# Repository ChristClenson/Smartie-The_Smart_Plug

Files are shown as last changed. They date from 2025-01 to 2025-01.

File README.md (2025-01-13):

# Smartie - Smart Plug Socket

This repository contains the details of **Smartie**, an innovative smart plug developed as part of the Semester 4 EN2160 Electronic Design Realization module. Smartie combines convenience, energy management, and safety features to create a versatile addition to any smart home setup.

<div align="center">
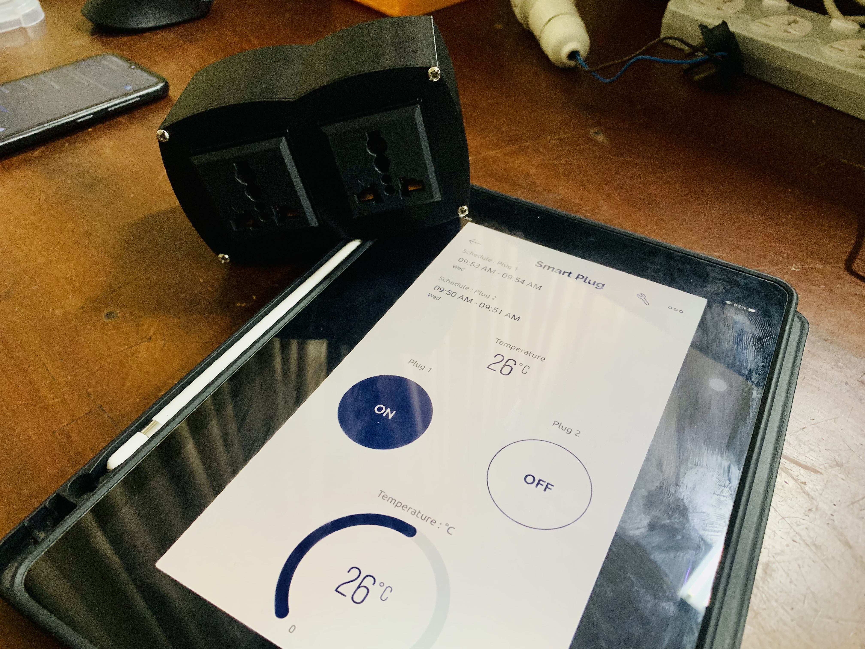
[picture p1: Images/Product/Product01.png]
Smartie
  
</div>

## Product Architecture
<div align="center">
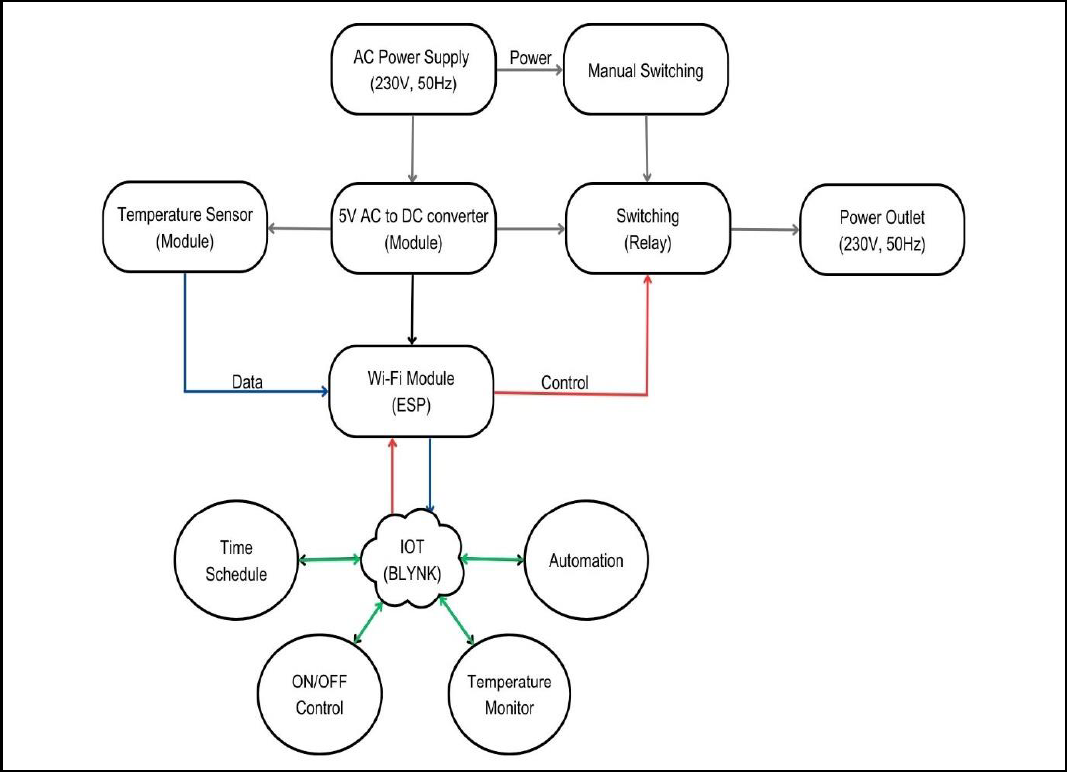
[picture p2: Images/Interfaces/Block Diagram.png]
Block Diagram
  
</div>

---

## Features

The **Smartie** smart plug offers a variety of advanced features designed for modern smart homes:

### 1. Wireless Control
Effortlessly manage devices and appliances remotely through a user-friendly mobile or web application. Whether at home or on the go, you can turn devices on or off with just a tap or click.

### 2. Temperature Monitoring
Keep track of the surrounding temperature in real-time via the mobile or web application. Monitor fluctuations and ensure optimal operating conditions.

### 3. Automatic Heating Protection
Ensure safety with the built-in heating protection feature. If the smart plug detects unusually high temperatures, it automatically cuts off power to the connected device to prevent hazards.

### 4. Time Scheduling
Set specific schedules for devices to operate automatically. From turning on the coffee maker in the morning to powering off devices at night, the scheduling feature helps save energy and simplifies daily routines.

---

## Purpose and Intended Usage

### 1. Remote Device Control
Control devices and appliances from anywhere using the mobile or web application. Turn devices on or off and monitor their status remotely, providing unparalleled convenience.

### 2. Energy Management
Optimize energy consumption by scheduling device usage. Reduce unnecessary power usage, lower utility bills, and contribute to a sustainable lifestyle.

### 3. Safety and Protection
Prevent overheating and electrical accidents with automatic heating protection. The plug continuously monitors the temperature and cuts off power when necessary, ensuring a secure environment.

---

## Target Users

- **Students**: Ideal for dormitories or apartments to efficiently manage devices and energy usage.
- **Homemakers**: Simplify daily routines and promote energy-saving practices.
- **Travelers**: Monitor and control home devices remotely for security and convenience.
- **Elderly or Disabled Individuals**: Increase accessibility and enable effortless device control.

---

## Mobile Application Specifications

The Smartie mobile application, powered by **Blynk 2.0**, enables seamless control and advanced functionality:

- Real-time remote control of devices.
- Temperature monitoring for safety and comfort.
- Automatic heating protection integration.
- Customizable time scheduling to optimize energy usage.

The application works in tandem with the **ESP8266 NodeMCU** and provides an intuitive interface for easy management of connected devices.

<div align="center">
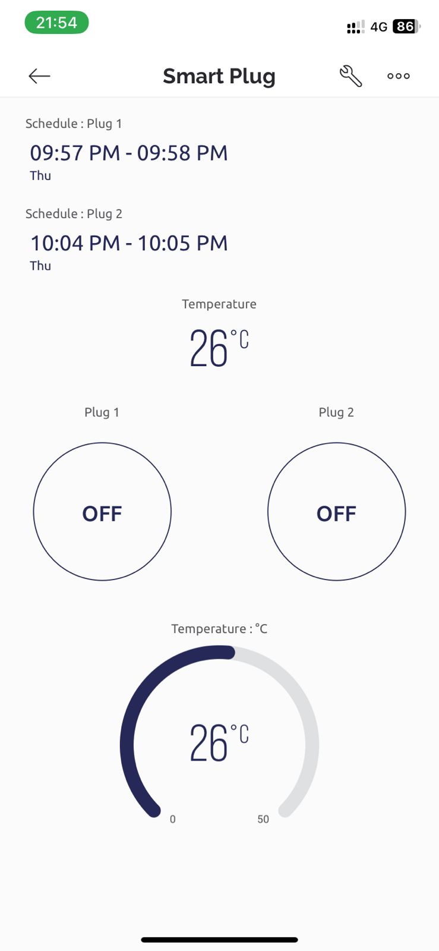
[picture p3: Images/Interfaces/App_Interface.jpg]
Blynk Interface
  
</div>

---

## Web Application Specifications

The Smartie web application, also powered by **Blynk 2.0**, extends device control to desktop or laptop browsers:

- Effortless control and monitoring of devices.
- Real-time status updates, temperature monitoring, and scheduling.
- Feature parity with the mobile application for a consistent user experience.

<div align="center">
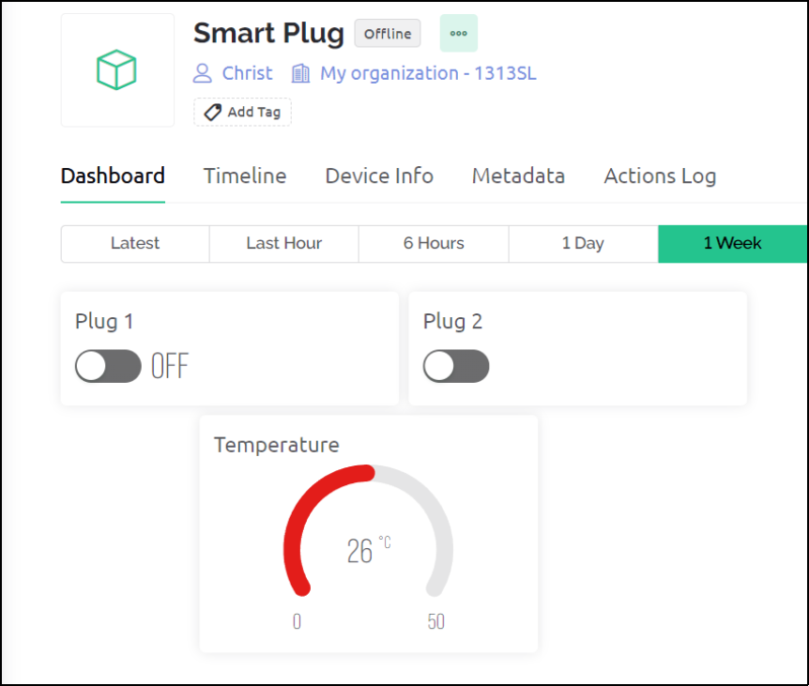
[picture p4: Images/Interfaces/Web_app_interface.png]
Web app Interface
  
</div>

---

## Technologies Used

- **ESP8266 NodeMCU**: Microcontroller for smart plug operation.
- **Blynk 2.0**: Platform for mobile and web application integration.
- **Temperature Sensor**: Monitors real-time temperature for safety features.

---
## Enclosure and PCB Designs

### Enclosure Design
<div align="center">
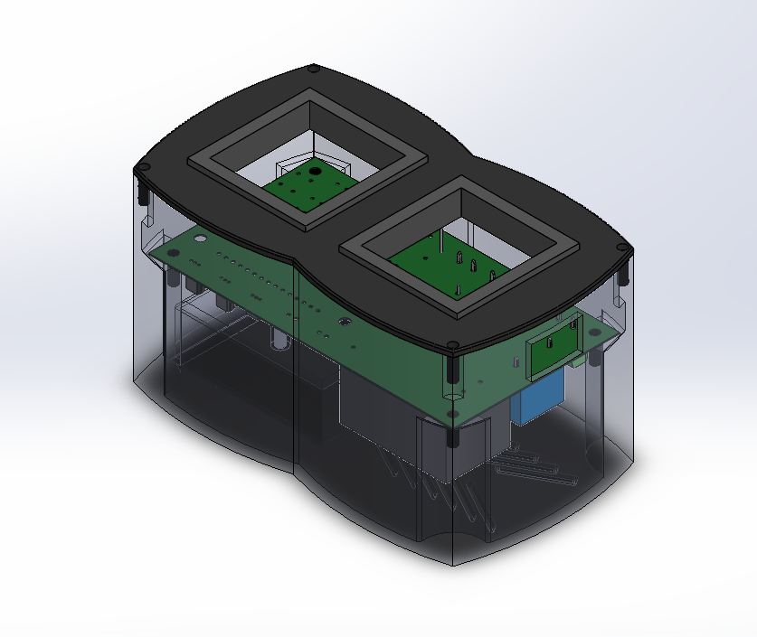
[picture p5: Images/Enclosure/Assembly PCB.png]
Enclosure
  
</div>

<div align="center">
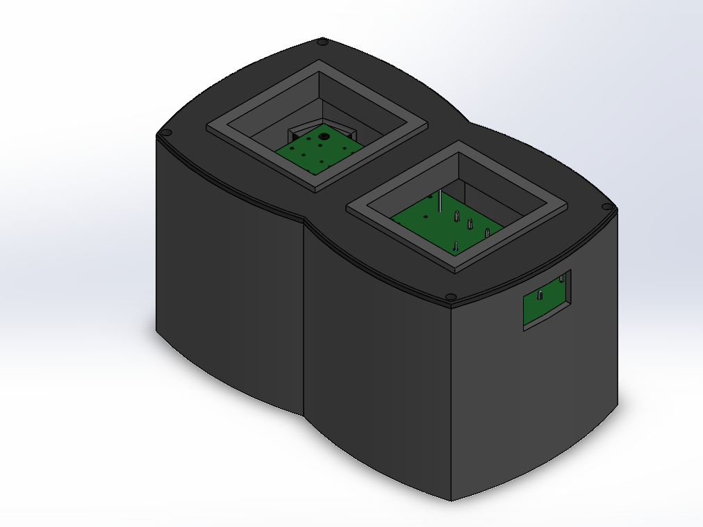
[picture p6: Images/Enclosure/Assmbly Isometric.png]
Enclosure
  
</div>

### PCB Design
<div align="center">
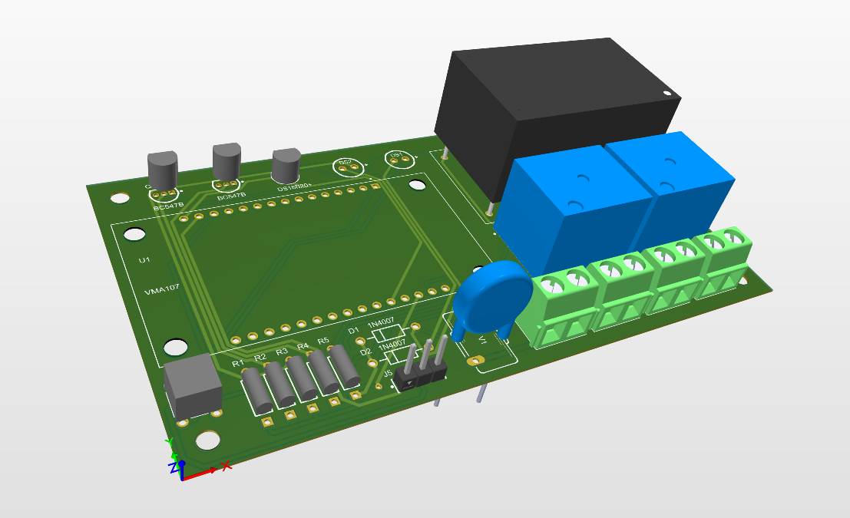
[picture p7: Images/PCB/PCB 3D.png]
PCB 3D
  
</div>

<div align="center">
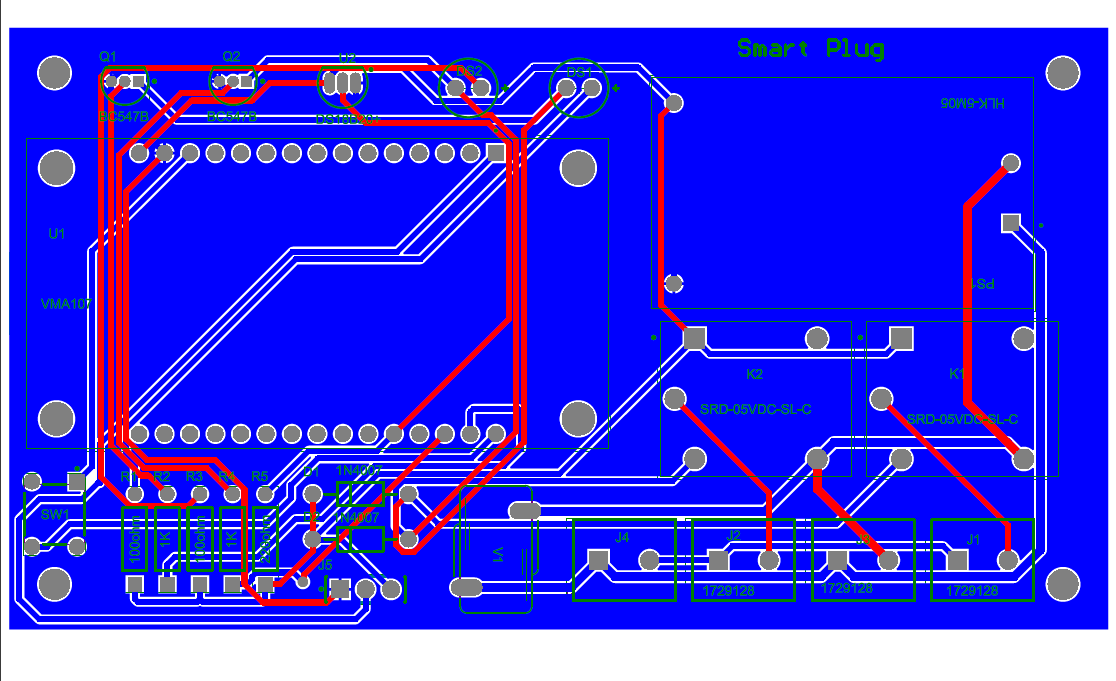
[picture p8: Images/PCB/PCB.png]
  
</div>

### Schematics Design
<div align="center">
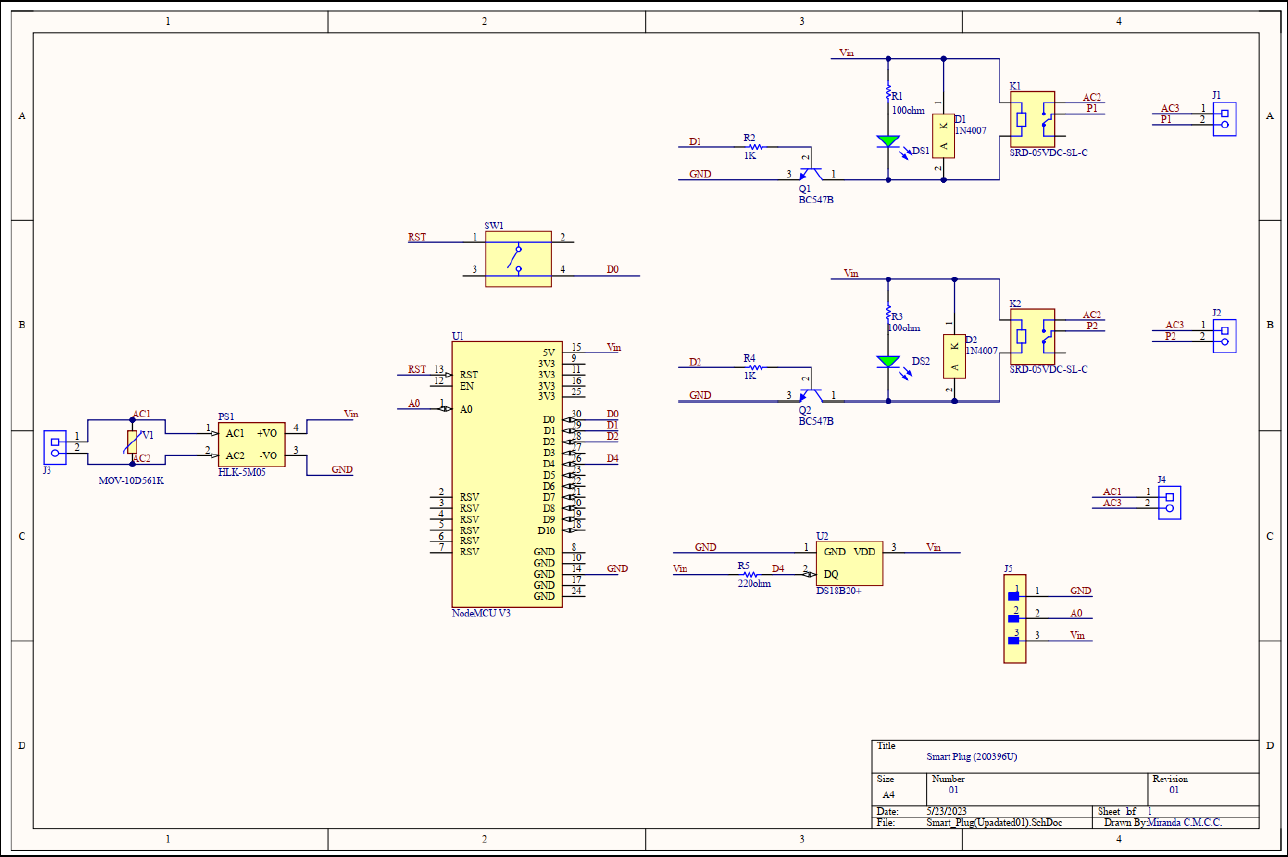
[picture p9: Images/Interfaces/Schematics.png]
  
</div>

---

## Conclusion

Smartie represents a significant step towards smarter and safer homes. With its innovative features, seamless control options, and focus on energy efficiency, it provides users with convenience, safety, and cost savings.

---

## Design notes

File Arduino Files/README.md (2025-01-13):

This directory contains the Arduino Code File for the Smart Plug.

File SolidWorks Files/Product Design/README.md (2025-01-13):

This directory contains the Enclosure Design Files of the Smart Plug.

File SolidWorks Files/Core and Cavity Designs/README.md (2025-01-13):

This directory contains the Core and Cavity Design Files for the Molds of the enclosure.

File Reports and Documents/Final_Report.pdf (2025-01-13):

## University of Moratuwa

## Department of Electronic and Telecommunication Engineering

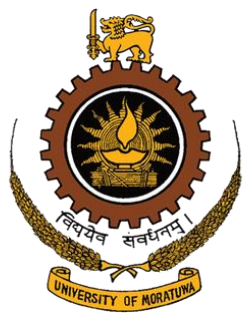
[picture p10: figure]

## EN2160 - Electronic Design Realization

## Final Report

Index No: 200396U

Name: Miranda C.M.C.C.

Product: Smart Plug

## 1. Abstraction

This report presents a concise overview of the smart plug's (also known as ‘Smartie’) development and assembly process. It includes the product description, specifications, schematics, BOM, PCB Gerber files, enclosure design, assembly instructions, and functionality testing procedures. This comprehensive guide serves as a valuable resource for understanding, replicating, and improving the smart plug's design.

Description and Specifications:

This section provides a detailed overview of the smart plug, including its functionality, target market, key features, and unique selling points. It also documents essential technical specifications, such as size, dimensions, hardware information and compatibility information.

Schematics, BOM, and PCB Gerber Files:

This section presents detailed circuit schematics for the smart plug, encompassing power supply and control circuitry. It includes a comprehensive Bill of Materials (BOM) with component names, part numbers, quantities, and sourcing information. Additionally, essential PCB Gerber files for manufacturing the printed circuit board are provided.

Enclosure Design Files:

This section provides a thorough description of the smart plug's enclosure design, featuring the 3D representations. It emphasizes user interface, material selection, and safety considerations.

Assembly and Installation Instructions:

This section offers a clear step-by-step guide for assembling the smart plug. It includes detailed instructions, accompanied by relevant images or diagrams. The assembly process covers component mounting on the PCB, enclosure assembly, and critical steps to build the final product. The installation instructions give the consumer the initial steps they need to follow to install the smart plug.

Functionality Testing:

This section outlines the testing process to ensure the smart plug's functionality. It includes procedures for verifying key features and compatibility with devices.

## Contents

## 2. Description and Specifications

## 2.1 Features

The 'Smartie' is an innovative smart plug socket that offers wireless control through a user-friendly mobile or web application. With advanced features such as temperature monitoring, automatic heating protection, and a convenient time scheduling feature, it's the perfect addition to any smart home setup.

Wireless Control:

With the 'Smartie' smart plug socket, we can effortlessly manage our devices and appliances remotely, providing us with enhanced convenience and control. Whether we're at home or on the go, mobile or web applications allow us to easily turn devices on or off with just a tap or click.

Temperature monitoring:

One of the standout features of the 'Smartie' is its temperature monitoring capability. We can use the mobile or web application to check the current temperature of smart plug’s surroundings and keep an eye on any fluctuations.

Automatic heating protection:

The 'Smartie' also comes equipped with automatic heating protection, providing an added layer of safety. If the plug socket detects unusually high temperatures, it will automatically cut off power to the connected device, preventing any potential hazards and ensuring peace of mind.

Time scheduling:

Additionally, the time scheduling feature allows us to set specific schedules for our devices. Whether it's turning on our coffee maker in the morning or automatically powering off our gaming console at night, we can customize the 'Smartie' to fit our daily routine. This feature helps us save energy, reduces utility bills, and adds convenience to our everyday life.

## 2.2 Purposes and Intendent Usage

Remote Device Control:

The primary purpose of Smartie is to provide users with the ability to remotely control their devices and appliances. Whether they're at home, at work, or away on vacation, they can easily manage their devices using the mobile or web application. This allows them to turn devices on or off, and monitor their status from anywhere, providing convenience and flexibility in managing their smart home.

Energy Management:

Smartie offers energy-saving benefits by allowing users to schedule device usage. With the time scheduling feature, they can set specific times for their devices to turn on or off automatically. This helps optimize energy consumption by ensuring that devices are only active when needed, reducing unnecessary power usage, and lowering utility bills.

Safety and Protection:

Smartie includes automatic heating protection mechanisms to ensure safety when using devices that generate heat. The plug socket continuously monitors the temperature, and if it detects excessively high levels, it will automatically cut off power to the connected device. This helps prevent overheating, reduces the risk of electrical accidents, and provides peace of mind for users.

## 2.3 Target Users

Students:

Students living in dormitories or apartments seek efficient ways to manage their devices, control energy usage, and enhance their living environment.

Homemakers:

Homemakers who are looking to simplify their daily routines, manage household devices remotely, and promote energy-saving practices.

Travelers:

Individuals who frequently travel and who want the ability to monitor and control their home devices remotely for security, energy efficiency, and convenience purposes.

Elderly or Disabled Individuals:

Smartie can offer increased accessibility and convenience for elderly or disabled individuals, allowing them to easily control devices without physical effort or mobility challenges.

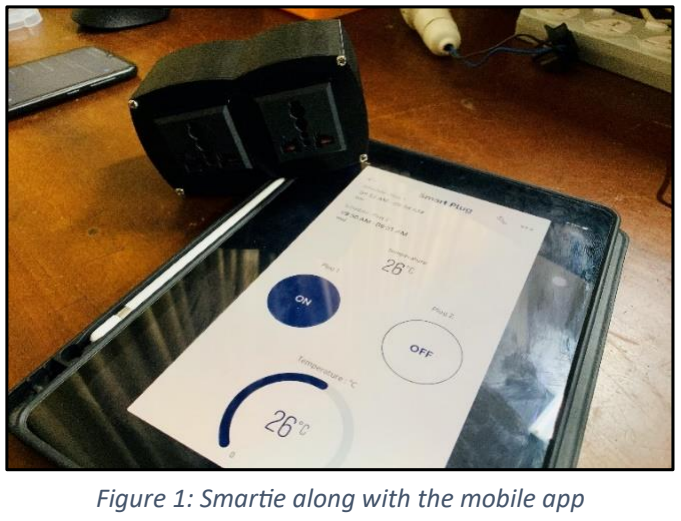
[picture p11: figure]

Figure 1: Smartie along with the mobile app

## 3. Product Specifications

## 3.1 Physical Specifications

- Dimension: 130mm x 70mm x 60mm
- Power inlet type: Square pin (Type G)
- Power outlet types: Square pin (Type G), Circular Pin (Type D)
- Development board: ESP 8266 NodeMCU

## 3.2 Development Board Specifications

The ESP8266 NodeMCU development board used in Smartie offers the following key specifications:

- ESP8266 Chip: Powered by the ESP8266 Wi-Fi module for wireless connectivity.
- Microcontroller: Includes a powerful microcontroller unit (MCU) for efficient

processing.

- Processing Power: Operates at up to 80MHz clock speed for fast execution of tasks.
- Memory: Provides onboard memory (4MB to 16MB) for program code and data

storage.

- GPIO Pins: Features GPIO pins for easy integration with external devices.
- Programming Interface: USB interface for programming and debugging.
- Arduino Compatibility: Arduino IDE compatibility for convenient development and

customization.

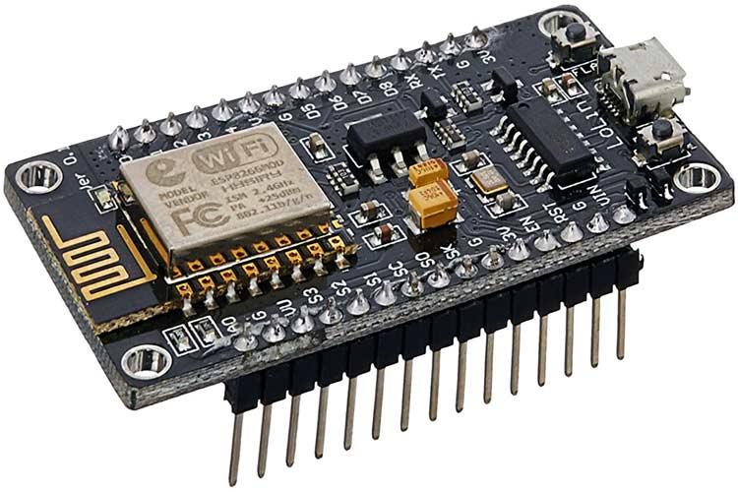
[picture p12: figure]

Figure 2: ESP8266 NodeMCU

## 3.3 Mobile Application specifications

The Smartie mobile application, powered by Blynk 2.0, brings seamless control and advanced features to our fingertips. Designed to work in tandem with the ESP8266 NodeMCU and Smartie's smart plug socket, this innovative application empowers us to effortlessly manage our devices and enhance our smart home experience.

The heart of the Smartie mobile application is Blynk 2.0, a powerful platform that enables intuitive and customizable control interfaces. With its user-friendly interface and extensive capabilities, Blynk 2.0 allows you to tap into the full potential of Smartie and its connected devices.

Through the mobile application, we gain real-time control over our devices, giving us the freedom to turn them on or off remotely with just a tap on our mobile screen. Whether we're at home or on the go, the convenience of managing our devices from the palm of our hand is now within reach.

It also integrates temperature monitoring functionality, providing us with instant access to real-time temperature readings. Stay informed about our surroundings and make informed decisions to maintain optimal comfort levels. With Blynk 2.0's seamless integration, Smartie can detect excessive temperatures and automatically cut off power to the connected devices, ensuring a secure environment for us and our home.

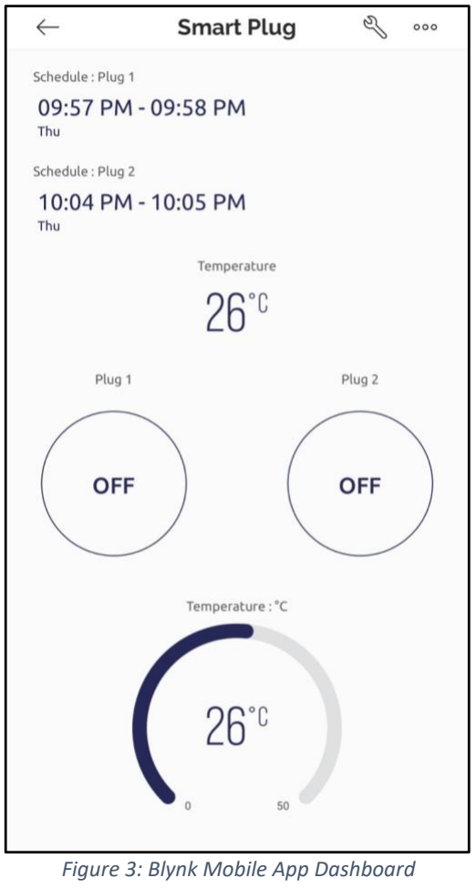
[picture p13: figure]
Figure 3: Blynk Mobile App Dashboard

## 3.4 Web Application specifications

Smartie web application, also powered by Blynk 2.0, which brings the same level of convenience and control to our desktop or laptop computer. With that we can seamlessly extend our device management capabilities beyond our mobile device and access them from the comfort of our web browser. Powered by the same robust Blynk 2.0 platform, the web application offers a familiar interface with additional functionalities and a larger screen real estate.

Just like its mobile counterpart, the web application allows us to effortlessly control and monitor our devices remotely. With a few clicks, we can turn devices on or off, adjust settings, and view real-time device status. Blynk 2.0's seamless integration ensures that the web application maintains feature parity with the mobile app. We can still benefit from temperature monitoring, automatic heating protection, time scheduling and notifications.

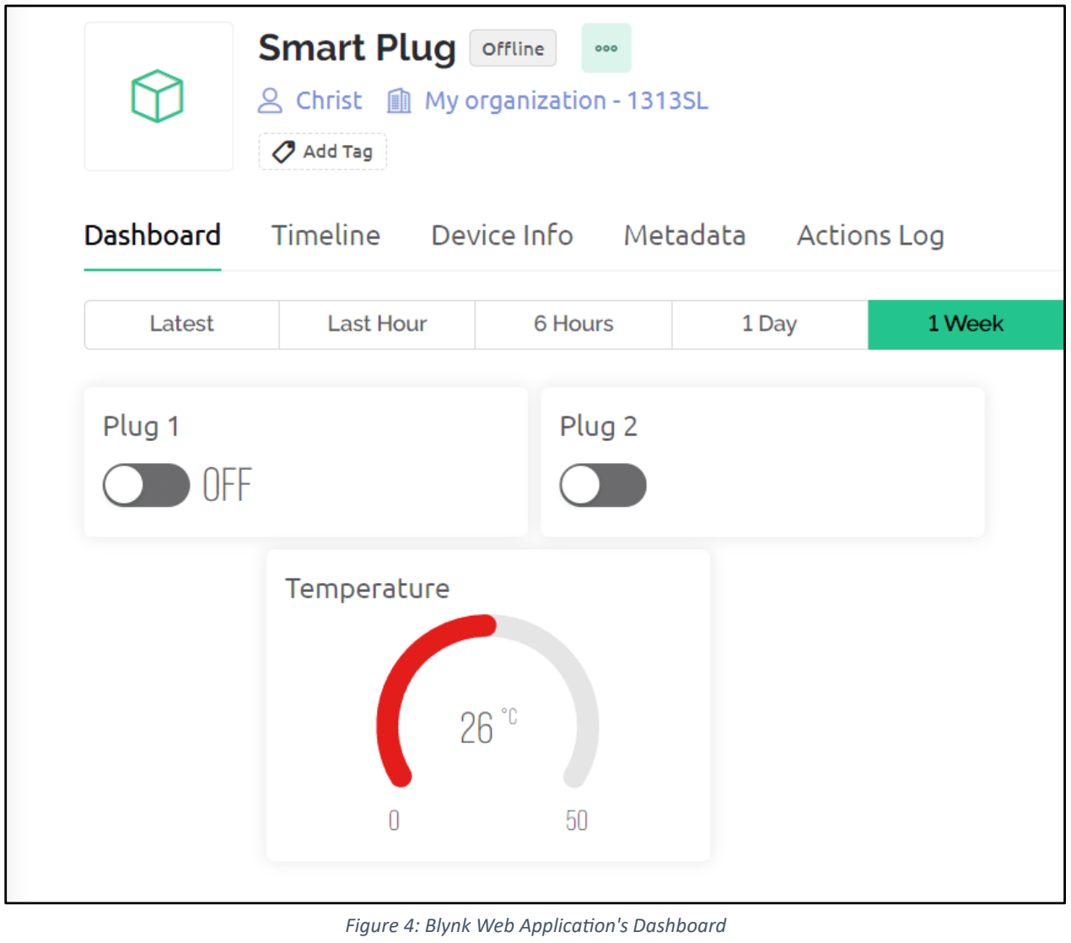
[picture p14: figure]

Figure 4: Blynk Web Application's Dashboard

## 4. Schematics, BOM, and PCB Gerber Files

## 4.1 Block Diagram

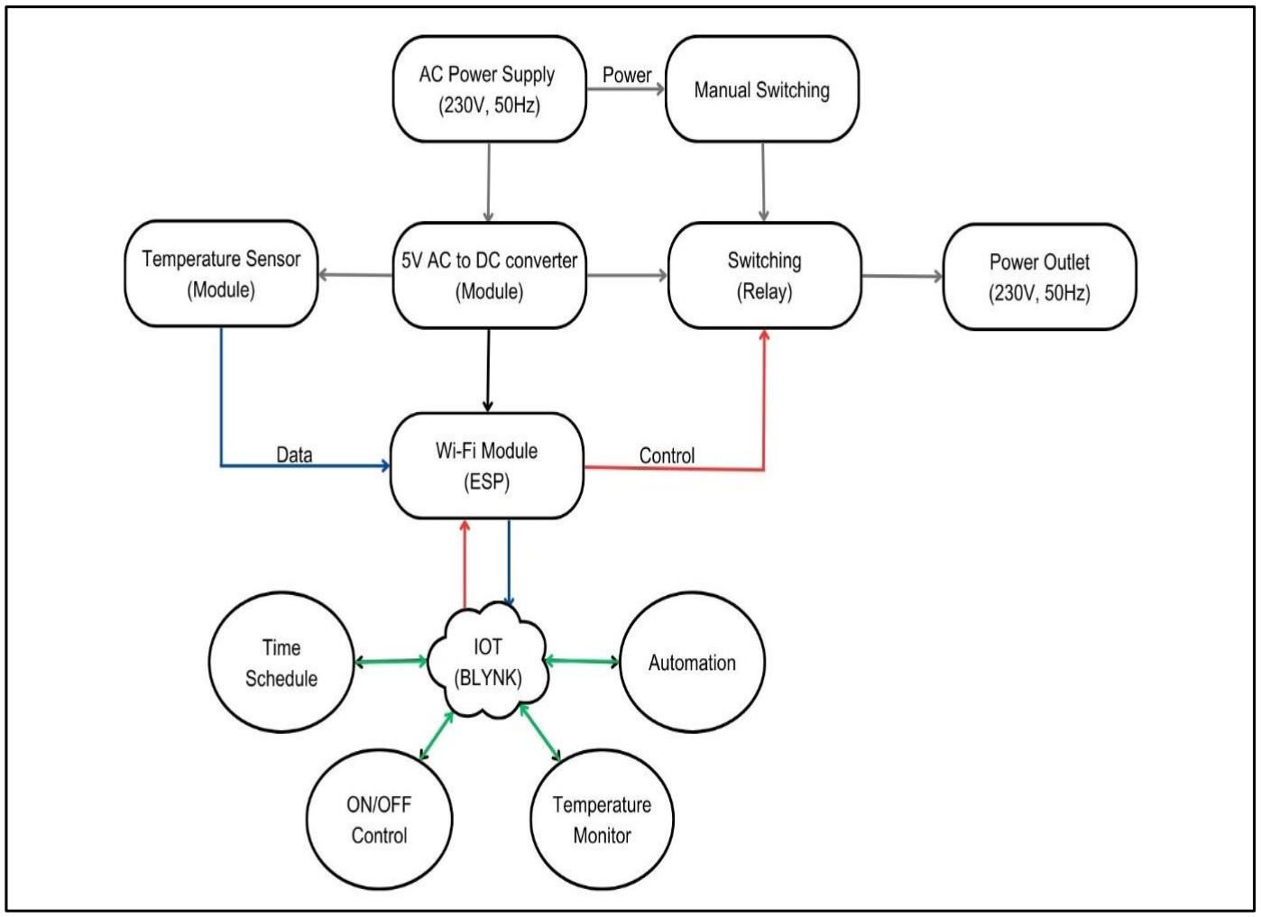
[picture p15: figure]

This is the initial block diagram that aligns with the product’s specifications. To ensure efficient power supply to the Wi-Fi module (ESP8266 NodeMCU), a single module that directly converts the 230V AC input to 5V DC is used. This approach not only contributes to a compact PCB design but also facilitates the overall compactness of the product. Consequently, it becomes more convenient to power both the Wi-Fi module and the temperature sensor within the smart plug.

The BLYNK IoT platform is used because of its user-friendly nature and simplistic user interface. This choice ensures easy setup and enhances the marketability of the product. Additionally, BLYNK offers all the desired features and functionalities I had envisioned for the smart plug.

## 4.2 Schematic Design

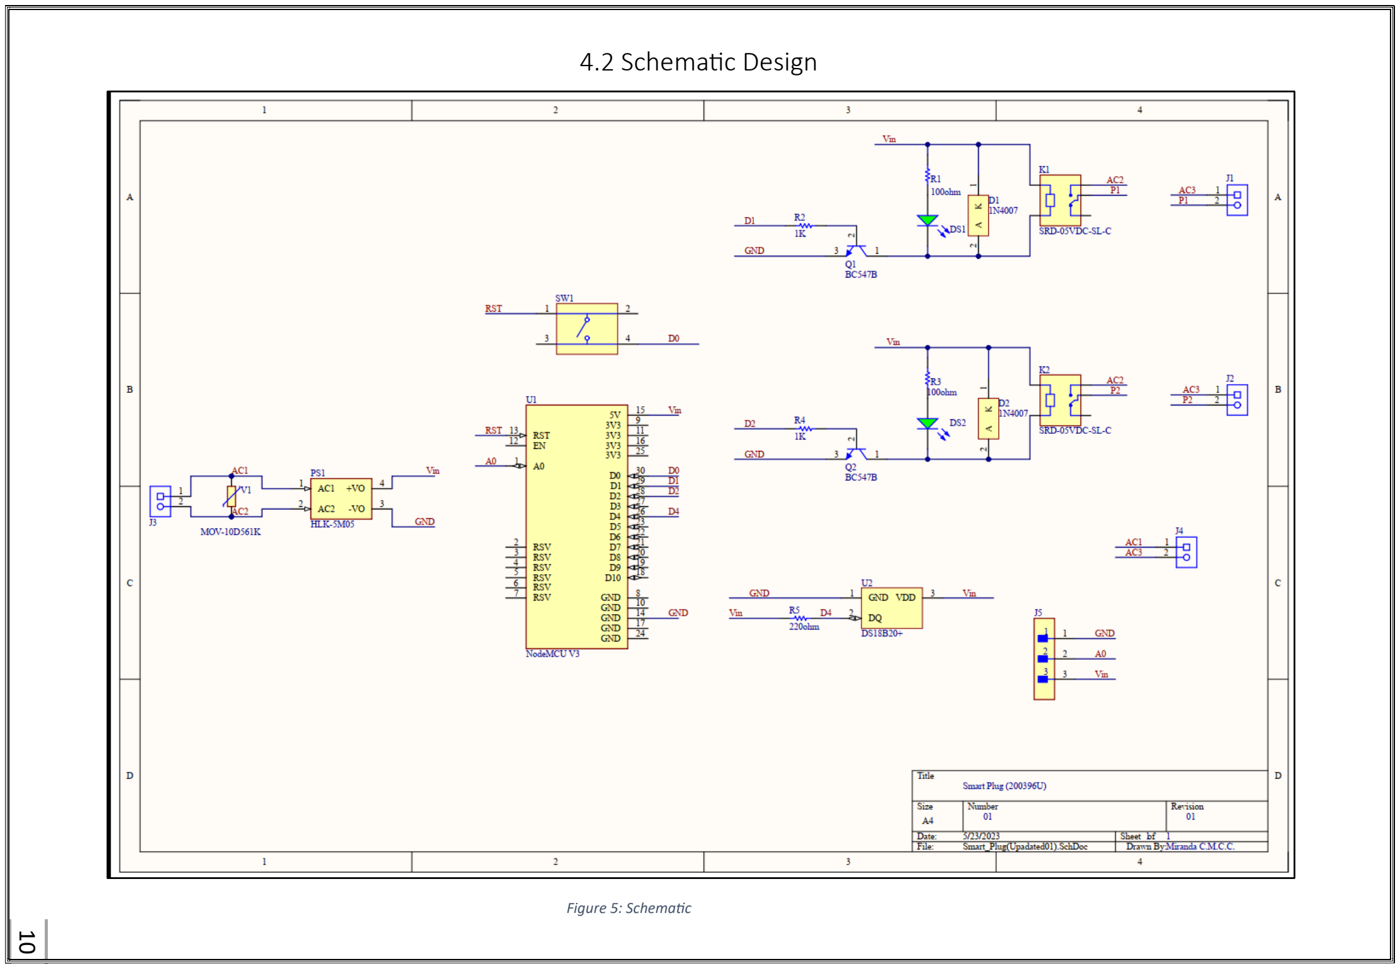
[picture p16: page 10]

Figure 5: Schematic

## 4.3 Bill of Materials (BOM)

Designator | Component | Model | Unit Price | Quantity | Total Price
U1 | Development Board | ESP8266 NodeMCU | 1000.00 | 1 | 1000.00
PS1 | 230V AC to 5V DC converter | HI-LINK HLK-5M05 | 890.00 | 1 | 890.00
K1, K2 | 5V Relay | Songle SRD-5VDC | 120.00 | 2 | 240.00
U2 | Temperature Sensor | MSKSEMI DS18B20 | 170.00 | 1 | 170.00
Q1, Q2 | Transistor | LGE BC547B | 10.00 | 2 | 20.00
V1 | Varistor | RUILON 10D561K | 20.00 | 1 | 20.00
D1, D2 | Diode | JUXING 1N4007 | 10.00 | 2 | 20.00
SW1 | Button Switch | Tactile Push Button | 20.00 | 1 | 20.00
R2, R4 | Resistor | 1KΩ | 2.00 | 2 | 4.00
R5 | Resistor | 220 Ω | 2.00 | 1 | 2.00
R1, R3 | Resistor | 100 Ω | 2.00 | 2 | 4.00
DS1, DS2 | LED | RED | 10.00 | 2 | 20.00
J1, J2, J3, J4 | Screw Terminal Block | 2 Pin | 30.00 | 3 | 90.00
Total Amount (Components only) | | | | | 2500.00

Components Cost:

The components have all been imported from abroad.

Components Cost = LKR 2500.00

Total Cost of Shipping = LKR 2500.00 (including VAT and other taxes)

Total Components Cost = LKR 5000.00

PCB Cost:

PCB was printed in JLC PCB, China.

PCB Printing Cost = LKR 1500.00

PCB Shipping Cost = LKR 2000.00 (including VAT and other taxes)

Total PCB Cost = LKR 3500.00

Enclosure Cost:

Enclosure was printed using 3D printing in Sri Lanka.

Printing Cost = LKR 4500.00

Shipping Cost = LKR 500.00

Total Enclosure Cost = LKR 5000.00

Total Cost:

Components = LKR 5000.00

PCB = LKR 3500.00

Enclosure = LKR 5000.00

Total Cost = LKR 13500.00

## 4.4 Supply Chain

No. | Component | Supplier
1. | Development Board (https://jdp-ic.en.made-in-china.com/product/MwZAjyqEQoVI/China-Nodemcu-Electronic-Development-Board-Esp8266-Wireless-WiFi-Module.html) | Shenzhen Jin Da Peng Technologies, China
2. 230V AC to 5V DC converter (https://www.lcsc.com/product-detail/Power-Modules_HI-LINK-HLK-5M05_C209907.html)
3. 5V Relay (https://www.lcsc.com/product-detail/Power-Relays_Ningbo-span-style-background-color-ff0-Songle-span-span-style-background-color-ff0-Relay-span-SRD-5VDC-SL-A_C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)
4. Temperature Sensor (https://www.lcsc.com/product-detail/Temperature-Sensors_MSKSEMI-DS18B20_C5379069.html)
5. Transistor (https://www.lcsc.com/product-detail/Bipolar-Transistors-BJT_LGE-BC547B_C713613.html)
6. Varistor (https://www.lcsc.com/product-detail/Varistors_RUILON-Shenzhen-Ruilongyuan-Elec-10D561K_C233178.html)
7. Diode (https://www.lcsc.com/product-detail/Diodes-General-Purpose_JUXING-1N4007_C3011149.html)
8. Button Switch (https://www.lcsc.com/product-detail/span-style-background-color-ff0-Button-span-Signal-Lamp-Main-span-style-background-color-ff0-Switch-span_BOCHEN-Chengdu-Gu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)
9. Resistor (https://www.lcsc.com/products/Through-Hole-Resistors_11239.html)
10. LED (https://www.lcsc.com/product-detail/Light-Emitting-Diodes-LED_Everlight-Elec-204-10SDRD-S530-A3-L_C84774.html)
11. Screw Terminal Block (https://www.lcsc.com/product-detail/span-style-background-color-ff0-Screw-span-span-style-background-color-ff0-terminal-span_Cixi-Kefa-Elec-KF331-5-0-2P_C6392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)

LCSC Electronics, China

## 4.5 PCB and Gerber

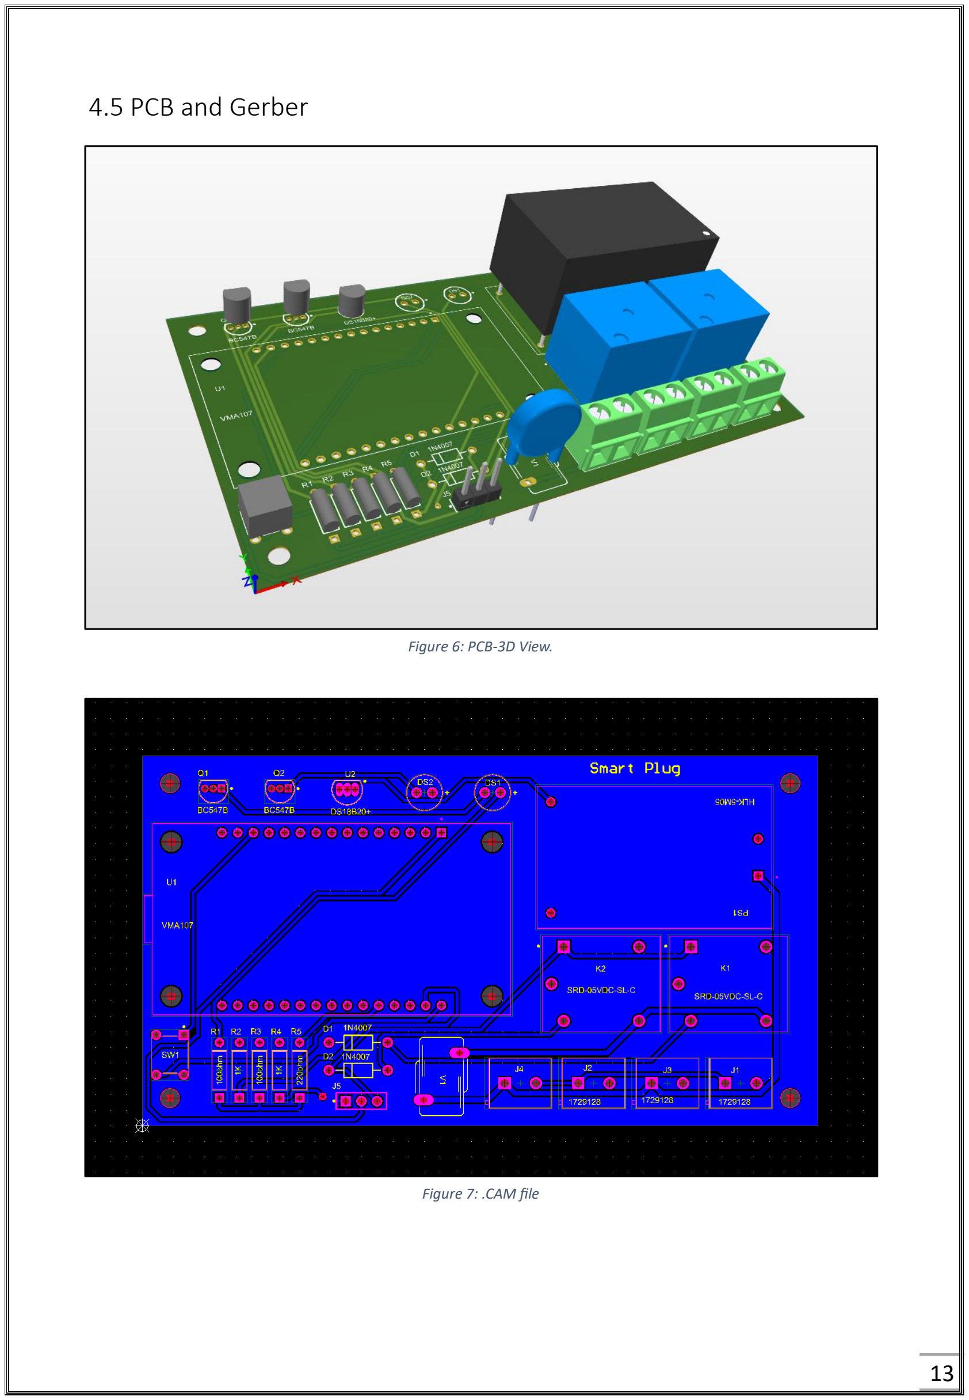
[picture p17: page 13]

Figure 6: PCB-3D View.

Figure 7: .CAM file

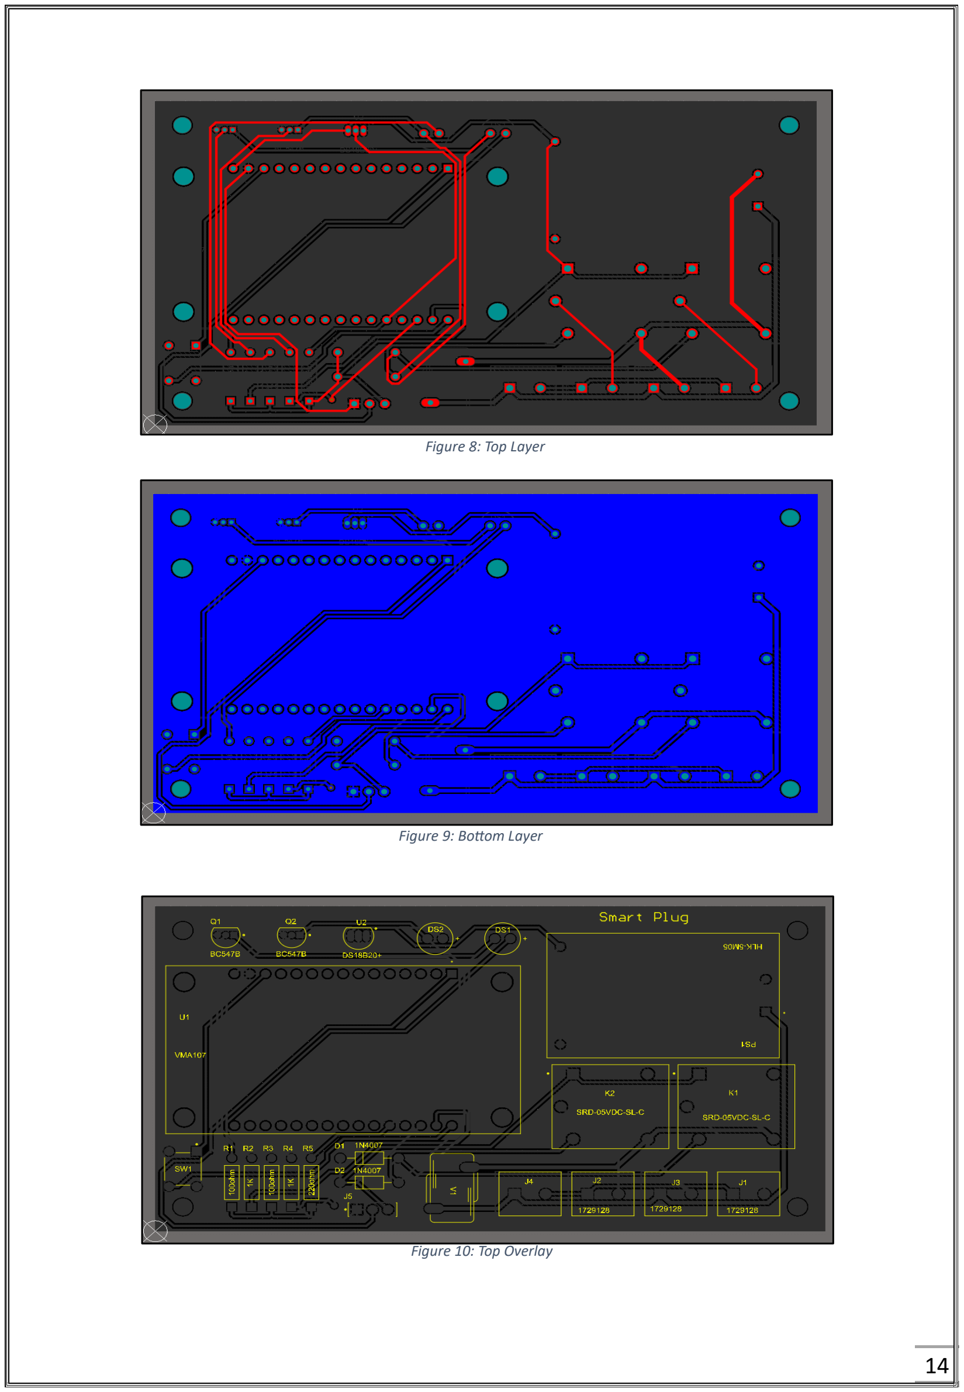
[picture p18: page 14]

Figure 8: Top Layer

Figure 9: Bottom Layer

Figure 10: Top Overlay

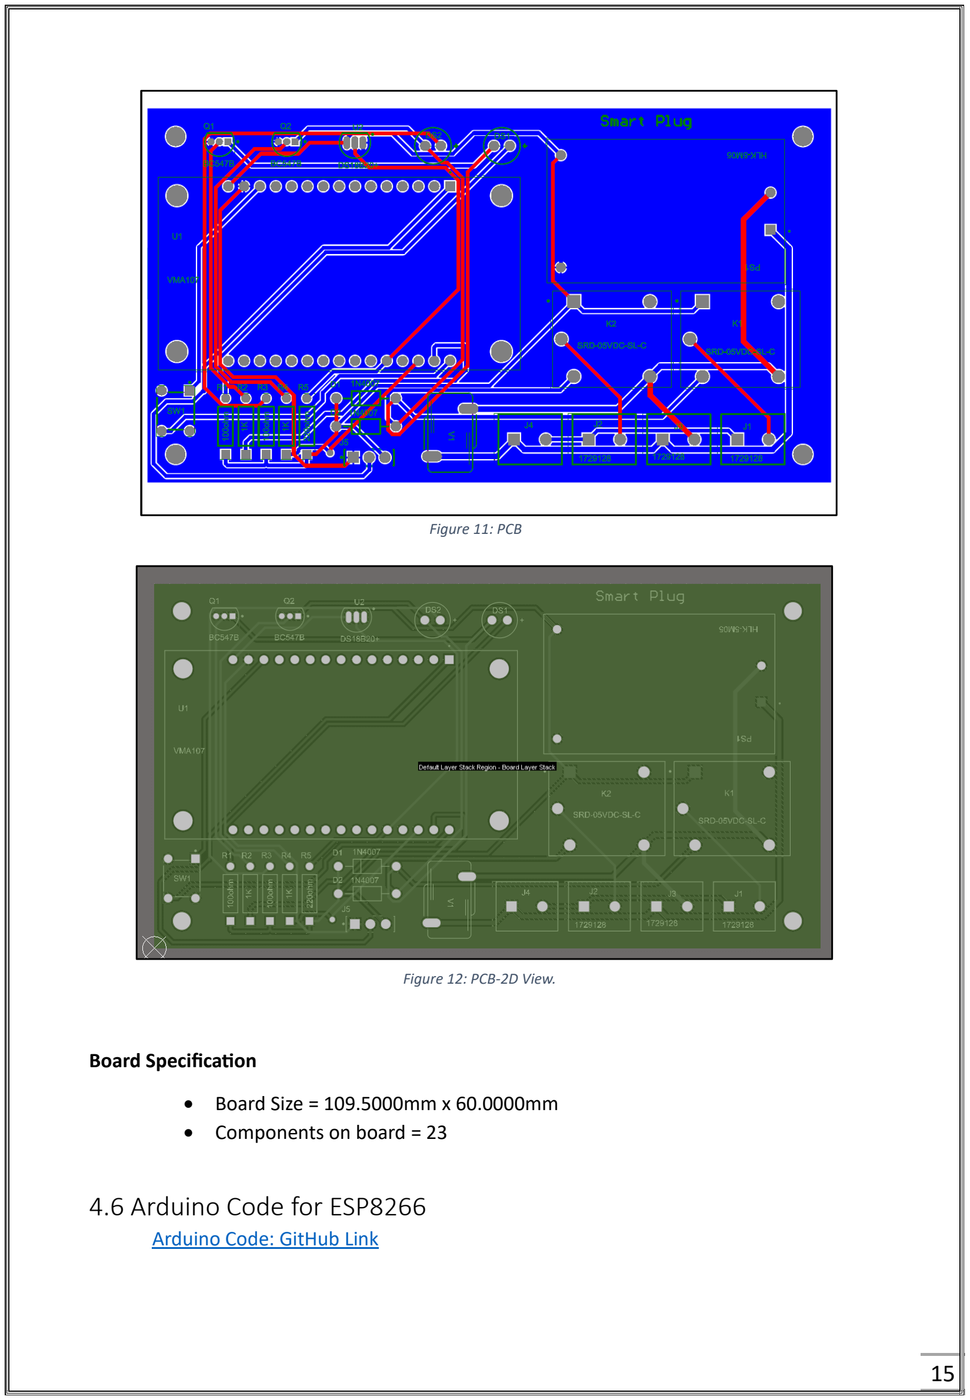
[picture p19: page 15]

Board Specification

- Board Size = 109.5000mm x 60.0000mm
- Components on board = 23

## 4.6 Arduino Code for ESP8266

Arduino Code: GitHub Link (https://github.com/ChristClenson/EN2160_Electronic_Design_Realization/tree/main)

Figure 12: PCB-2D View.

Figure 11: PCB

## 5. Enclosure Design Files

## 5.1 Hand-drawn Sketches

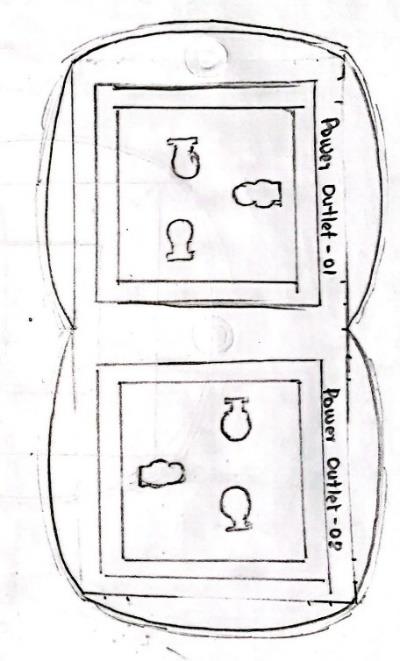
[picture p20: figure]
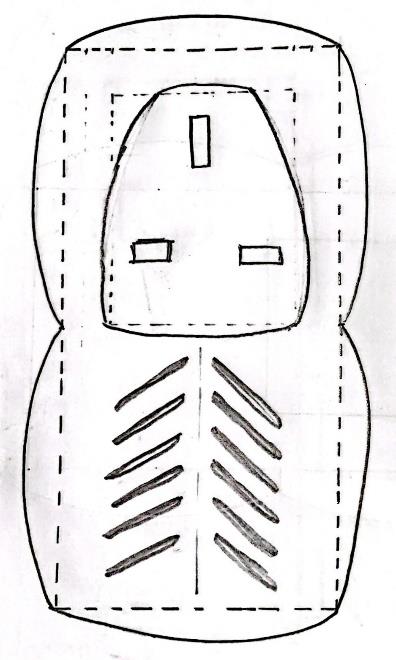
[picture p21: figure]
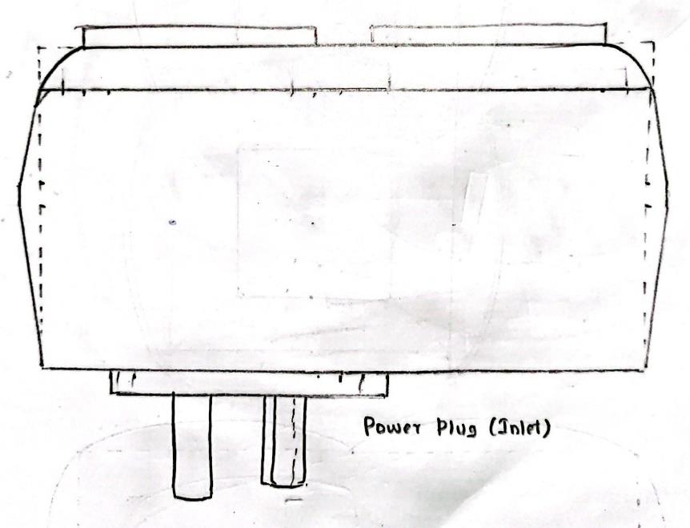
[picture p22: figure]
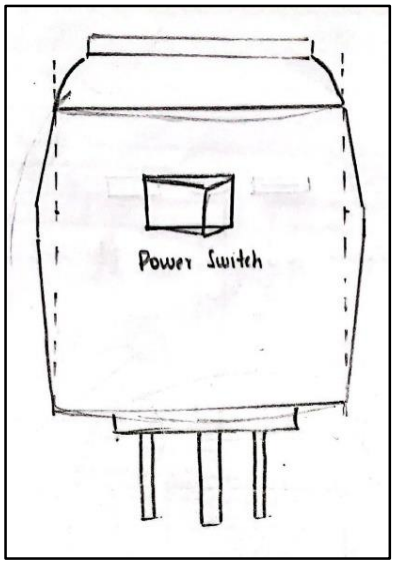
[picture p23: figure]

This design aimed to address the limitations of traditional multiplugs commonly used in our daily lives. Many of those multiplugs lack multiple outlets and a convenient power switch. So that I chose this design featuring two power outlets, along with a shared power switch for simultaneous control.

Furthermore, as the outlets were placed vertically, they are positioned in opposite directions to prevent any potential collision between connected plugs. To ensure proper airflow and prevent overheating, air vents have been incorporated into the design.

## 5.2 Bottom Case – SolidWorks

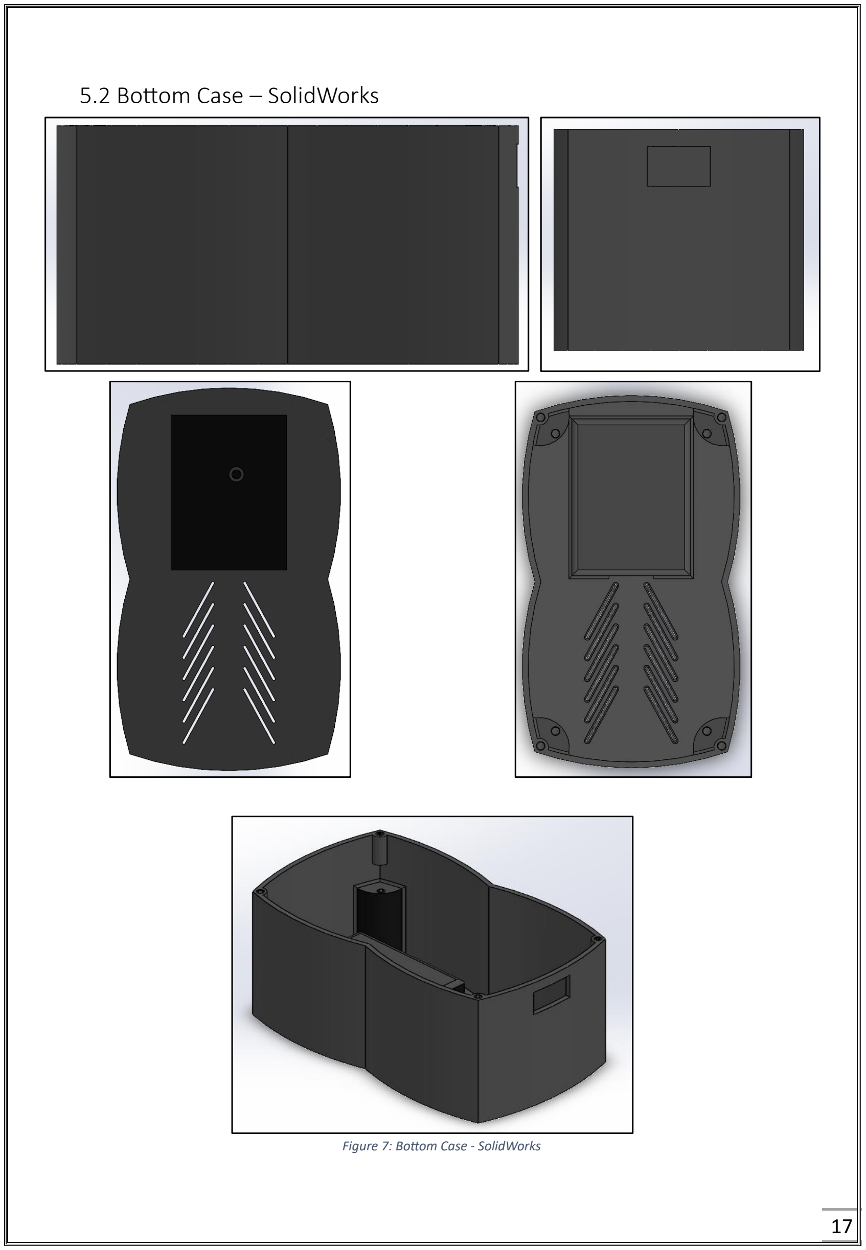
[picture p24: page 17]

Figure 7: Bottom Case - SolidWorks

## 5.3 Top Lid – SolidWorks

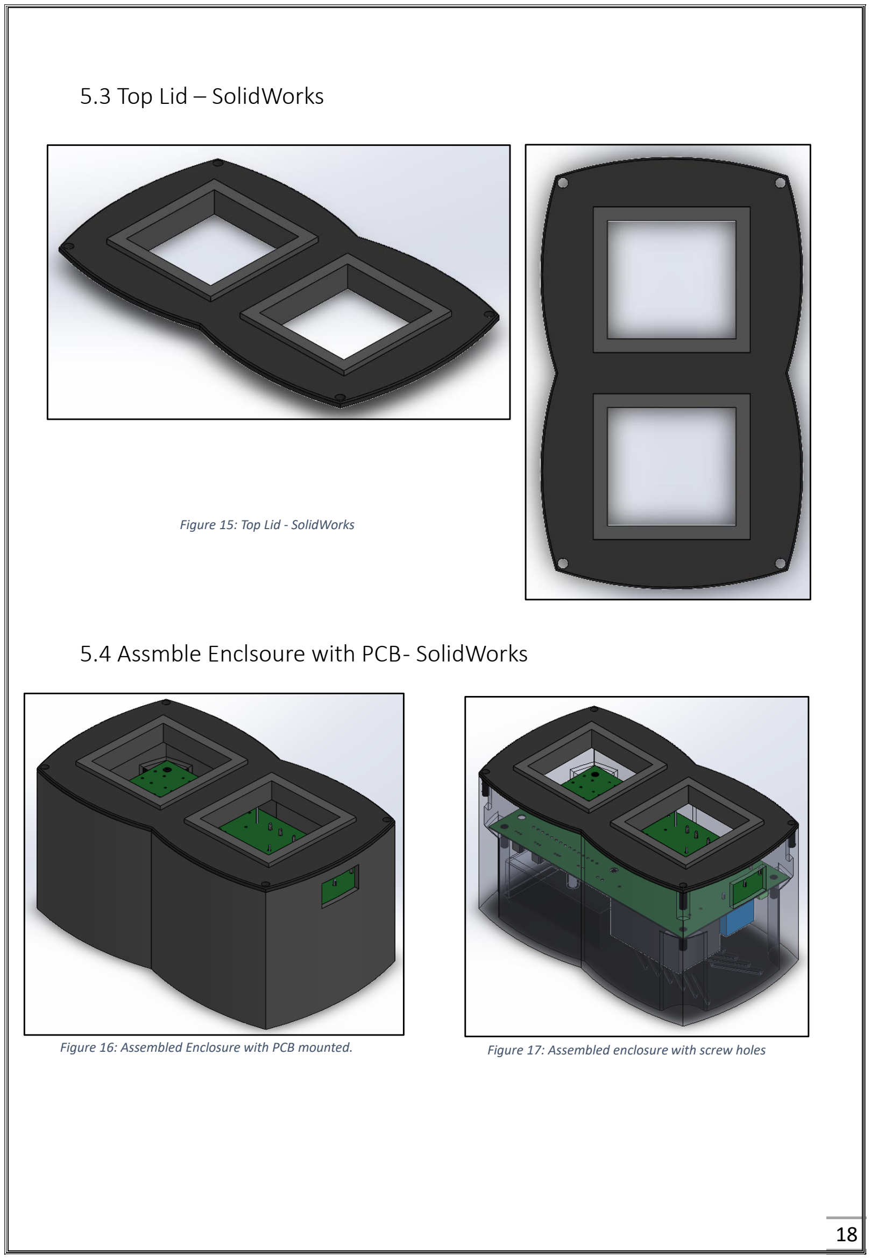
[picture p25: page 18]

## 5.4 Assmble Enclsoure with PCB - SolidWorks

Figure 15: Top Lid - SolidWorks

Figure 16: Assembled Enclosure with PCB mounted. | Figure 17: Assembled enclosure with screw holes

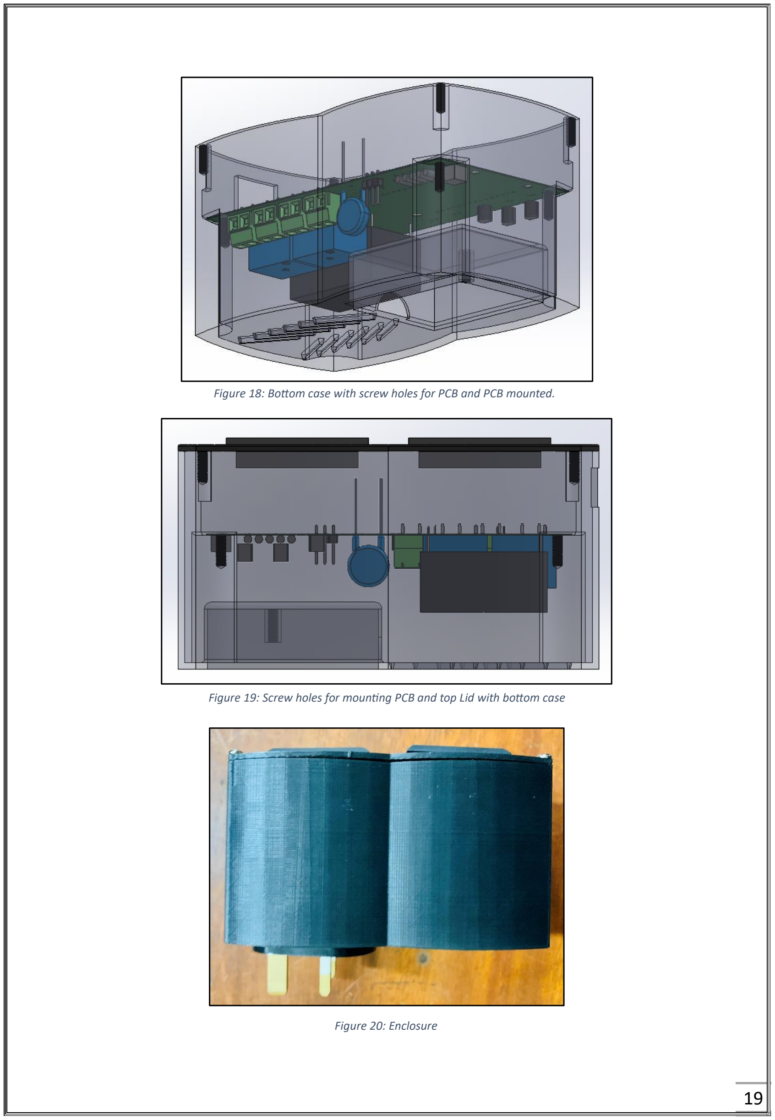
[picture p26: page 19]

Figure 18: Bottom case with screw holes for PCB and PCB mounted.

Figure 19: Screw holes for mounting PCB and top Lid with bottom case

Figure 20: Enclosure

## 5.5 User Interface

The ‘Smartie’ is designed with a minimalist enclosure, focusing on convenience and seamless integration into a smart home ecosystem. While the primary user interface lies in the mobile and web applications, I’ve paid attention to the enclosure's subtle details to enhance the overall experience.

Sleek Power Switch:

On the front of the ‘Smartie’, there’s a smooth, easy-to-use power switch. With just a gentle flick, we can conveniently disconnect power to both power outlets, ensuring maximum safety and energy efficiency.

Dual Power Outlets:

The ‘Smartie’ features not just one but two power outlets. Designed to make the most out of its vertical form, the outlets are thoughtfully positioned in opposite directions, one facing left and the other right. This unique layout allows for efficient usage of space and ensures that you can plug in two devices without any hassle. Whether it's a Type G (Square Pin) or Type D (Circular Pin) plug, both fit seamlessly into the outlets, accommodating various input devices.

Universal Power Inlet:

Located at the back of the ‘Smartie’, you'll discover a square pin power inlet. Universally compatible with the standard wall sockets prevalent in most homes in Sri Lanka, this feature makes the Smart Plug the perfect companion for local distribution.

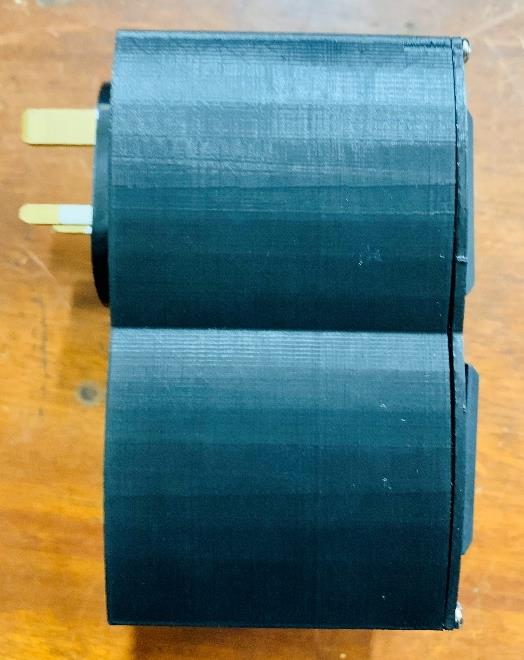
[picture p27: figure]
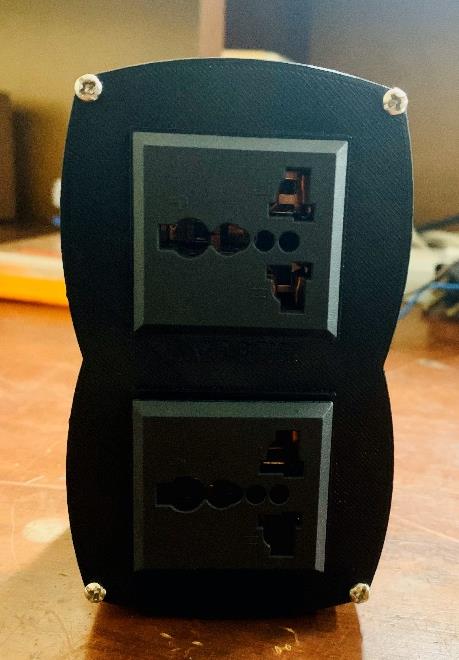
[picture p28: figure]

Figure 21: User Interface (Power Inlet and Power Outlets)

## 5.6 Material Selection for Enclosure

When creating the enclosure for a smart plug, choosing the right materials is crucial to guarantee its strength, safety, and overall effectiveness. Initially, for the prototype, I used 3D printing to manufacture the enclosure. However, for mass production, we need to explore more professional manufacturing methods such as injection molding. In this process, the following factors must be taken into consideration:

Heat Resistance:

The material should have good heat resistance to withstand the heat generated by the electrical components within the enclosure. This is crucial to prevent warping or deformation and maintain the structural integrity of the smart plug.

Impact Resistance:

The enclosure should be able to withstand accidental impacts or drops without cracking or breaking. This ensures the safety of both the user and the internal electronics.

Electrical Insulation:

The chosen material must provide proper electrical insulation to prevent any electrical leakage or short-circuits that could be hazardous to users or connected devices.

Environmental Considerations:

The material should be environmentally friendly and, if possible, recyclable to minimize its impact on the environment.

## 5.7 Safety Considerations for Enclosure

Proper Insulation:

To ensure safety and minimize the risk of electric shocks, the enclosure must offer sufficient insulation to prevent direct contact with live electrical components. To achieve this, heat sleeves have been incorporated into all connections within the enclosure. These heat sleeves act as protective barriers, safeguarding users from any potential electrical hazards.

Ventilation and Heat Dissipation:

Sufficient ventilation is a crucial aspect of the enclosure design to prevent internal components from overheating, especially when the smart plug supports high-power devices. To address this, air vents have been strategically incorporated at the bottom of the product, ensuring a continuous and ample airflow within the device. This effective ventilation system helps maintain optimal operating temperatures and enhances the overall performance and safety of the smart plug.

## 6. Assembly and Installation Instructions

## 6.1 Assembly Instructions

For manufacturers, the installation process involves several steps to ensure a successful assembly:

Components placing on the PCB:

Begin by placing the components on the PCB with precise orientation and appropriate values. While all components used are through-hole, consider incorporating surface mount components to enhance PCB compactness without compromising product functionality.

Mounting PCB in the enclosure:

Once the enclosure is ready, typically through 3D printing, (For bulk production they will be made via molding procedure) securely mount the PCB using screws and a beam-like structure inside the enclosure. To maintain compactness, position the PCB upside down within the enclosure.

Basic Wiring:

Proceed with the proper wiring, connecting the inlet plug to the PCB. Integrate a control switch into the circuit to enable manual control functionality. This will be done using the live wire connectivity.

Installing power outlets:

Install the power outlet on the top lid with utmost care for orientation. Connect the Neutral wire from the appropriate connector on the PCB in parallel with the outlets. Similarly, connect the Live wire. For safety, directly link the earth wire from the inlet plug to the power outlets.

Placing Inlet Plug:

Carefully place the inlet plug into its designated slot and secure it with a screw for stability.

Finishing:

Finally, close the top lid, securing it with 3mm tap-in screws for a polished finish.

By following these steps diligently, the manufacturing process will result in a high-quality product that meets both functionality and aesthetic requirements.

## 6.2 Installation Guide

The installation process for Smartie is straightforward and user-friendly. Upon purchasing the product, customers are required to establish a connection between Smartie and either a mobile hotspot or a Wi-Fi router. It is crucial to note that Smartie operates exclusively on a 2.4GHz network band. Consequently, users must ensure compatibility with this specific frequency range before proceeding with the setup process.

The procedure is,

1. To begin the installation process, download the Blynk application from either the App

Store or the Play Store.

2. Proceed with creating a Blynk account by completing the registration process. Once

successfully registered, sign in to your Blynk account using the provided credentials.

3. To get started, simply plug your Smart Plug into any standard wall socket.
4. To initiate the setup process, navigate to the device search option.

(Before proceeding, ensure that the Wi-Fi network you intend to connect the smart

plug to is active and operational. Additionally, it is essential that the device you are

utilizing to search for the smart plug is connected to the same Wi-Fi network.)

5. Once the smart plug device has been successfully detected during the search process,

simply select, and connect to it.

(This will establish a secure and reliable connection between your device and the

smart plug. With this connection established, you are now ready to enjoy the full

functionality and convenience that the smart plug offers.)

6. Take full advantage of the customization options available to you and personalize your

dashboard according to your preferences.

7. Enjoy the convenience of accessing and controlling your smart plug from any device or

web application by simply logging in to your Blynk account.

With this seamless integration, you gain the ability to manage your smart plug effortlessly from the comfort of your preferred device or through the user-friendly web interface. Whether you're at home, at work, or on the go, the power to control and monitor your smart plug is always at your fingertips.

Reference: Blynk.Documentation (https://docs.blynk.io/en/legacy-platform/legacy-articles/nodemcu)

## 7. Functionality Testing

These are the results of the functionality testing conducted on ‘Smartie’. The purpose of these tests is to ensure that the smart plug performs its intended functions accurately and reliably. The tests were conducted in a controlled environment to simulate real-world usage scenarios.

On/Off Functionality:

Test Procedure:
The smart plug was connected to various devices, including lamps, chargers, and electronic gadgets, to verify the on/off functionality.
Test Result:
The smart plug successfully turned connected devices on and off as expected, both through the mobile app and the web app.

Compatibility Testing:

Test Procedure:
The smart plug was tested with devices of different power ratings to check for compatibility.
Test Result:
All devices tested, ranging from 50W to 1500W, were compatible with the smart plug, and it handled varying loads effectively.

Communication with Mobile App:

Test Procedure:
The smart plug was paired with the Blynk app, and commands were sent to control the plugs remotely.
Test Result:
The mobile app communicated seamlessly with all five smart plugs, and commands were executed promptly without any failures.

Timer and Scheduling:

Test Procedure:
The timer and scheduling features were tested by setting the plugs to turn devices on/off at specified times.
Test Result:
All smart plugs adhered to the predefined schedules, and devices were switched on/off at the correct times consistently.

Overheating Protection:

Test Procedure:
The smart plugs were tested under continuous high-load conditions to evaluate overheating protection.
Test Result:
All smart plugs effectively detected overheating and shut down to prevent potential fire hazards.

Based on the functionality testing results, ‘Smartie’ has demonstrated excellent performance and reliability. All key features, including on/off functionality, timer, scheduling, and safety mechanisms, functioned flawlessly. The smart plug exhibited compatibility with a wide range of devices and maintained stable Wi-Fi connectivity within a reasonable range. The remote-control capabilities and manual operation provided users with convenient control options. Overall, the smart plug meets the highest standards for quality, functionality, and safety.

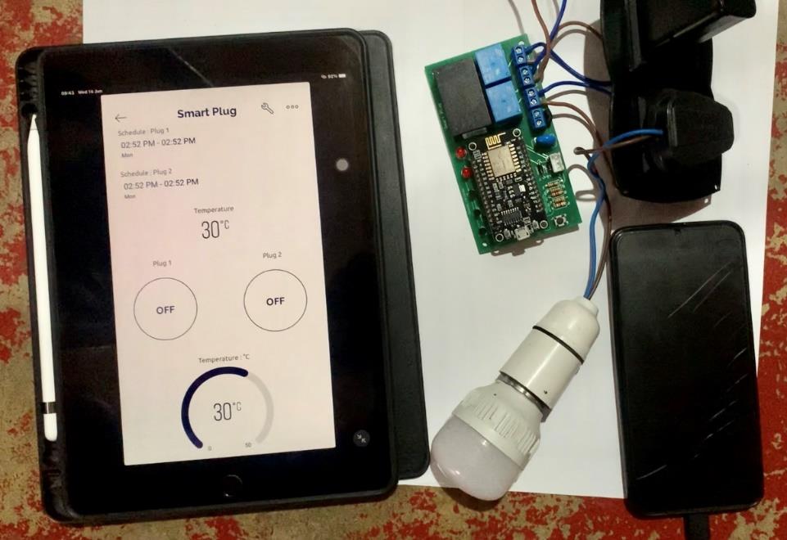
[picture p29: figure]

## 8. Summary and Conclusion

During the initial stages of development, I successfully implemented several exciting features for the smart plug, as mentioned in the introduction. However, due to certain technical challenges, I couldn't achieve all the planned and recommended features. Nevertheless, I am committed to continuously improving the product, and here are some future upgrades that I am considering:

Voice Control:

I understand the importance of voice control for seamless user experience. Therefore, integrating the smart plug with popular voice assistants like Alexa and Google Voice Assistant will be a much-needed upgrade. With this upgrade, users will be able to control the plug's functionalities using simple voice commands.

Enhanced Charging Options:

Incorporating both USB-C and USB-A outlets into the smart plug will be a valuable addition. This addition will enable users to charge a wider range of devices simultaneously, catering to various charging needs.

Separate Power Switches:

To offer greater manual control and convenience, it’ll be more useful to add individual power switches for each outlet on the smart plug. This way, users can turn on/off specific devices connected to the plug without affecting others.

Power Monitoring Features:

Recognizing the growing demand for energy efficiency, developing power monitoring capabilities for the smart plug will be more appropriate. This feature will allow users to track energy consumption of connected devices and gain insights into their power usage, promoting responsible energy practices.

## 9. Bibliography

1. Inclusive Design Toolkit – Cambridge University (http://www.inclusivedesigntoolkit.com/GS_overview/overview.html)
2. ESP8266 NodeMCU Datasheet (https://www.espressif.com/sites/default/files/documentation/0a-esp8266ex_datasheet_en.pdf)
3. Blynk Documentation (https://docs.blynk.io/en/)
4. 230V AC to 5V DC converter Datasheet (https://www.hlktech.com/en/Goods-16.html)

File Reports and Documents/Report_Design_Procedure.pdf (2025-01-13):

## University of Moratuwa

## Department of Electronic and Telecommunication Engineering


## EN2160 - Electronic Design Realization

Report – Design Procedure

Index No: 200396U

Name: Miranda C.M.C.C.

Product: Smart Plug

## 1. Abstraction

This report presents a comprehensive overview of the design procedures involved in the development of "Smartie," the smart plug socket with advanced features for home automation. The design process encompasses three key stages: conceptual design, preliminary design, and detailed design.

The conceptual design phase involves identifying the requirements and desired functionalities of Smartie. Extensive research and analysis are conducted to understand user needs and market trends. Various concepts and ideas are generated, evaluated, and refined to establish the foundation for the product's design.

The preliminary design stage focuses on translating the selected concept into a tangible product. This phase involves creating design sketches, 3D models, and prototypes. Factors such as wireless connectivity, control mechanisms, and compatibility with mobile and web applications are thoroughly considered and integrated into the preliminary design.

In the detailed design phase of Smartie's development, basic design procedures are followed to ensure the successful manufacturing of the product. These procedures include schematics, programming codes, component selection and bill of materials and the supply chain. By following these basic detailed design procedures, Smartie's design is refined and prepared for the manufacturing phase. These procedures help ensure that the product is designed to meet functional requirements, can be manufactured efficiently, and performs reliably.

## Contents

## 2. Conceptual Design

During the design phase, I engaged in fruitful discussions with my colleagues to explore initial ideas, seeking their valuable input. Additionally, we diligently gathered feedback from users regarding these ideas. This collaborative effort allowed us to refine our concepts and subsequently develop detailed enclosure sketches and block diagrams for the proposed product.

To ensure an objective assessment of the various options, I employed a selection matrix for both the sketches and block diagrams. This approach enabled me to evaluate each design based on predetermined criteria, facilitating an informed decision-making process. After careful analysis, I identified the most promising design from the selection matrix for further progression.

With the selected sketch and block diagram as my foundation, I have seamlessly transitioned to the next stage of the design phase. This progression marks an important milestone as I move closer towards materializing our vision into a tangible and functional product.

The Conceptual Design phase encompasses two key approaches: the Design-Driven Innovation approach and the User-Centered Design approach. Each approach brings unique perspectives and plays a vital role in shaping the final product.

The Design-Driven Innovation approach involved harnessing the creative insights of my colleagues. Through collaborative discussions, we explored various design ideas, capitalizing on our collective expertise and ingenuity. This approach allowed us to think beyond conventional boundaries, fostering innovative concepts and solutions.

Conversely, the User-Centered Design approach placed the users at the heart of the design process. By actively seeking and gathering feedback from users, we ensured that their needs, preferences, and expectations were thoroughly understood and incorporated into the design. This empathetic approach ensured that our final product would not only be visually appealing but also highly functional and intuitive for its intended users.

By blending the inputs from both colleagues and users, we were able to strike a harmonious balance between creativity and practicality. The synergy between the Design-Driven Innovation and User-Centered Design approaches has propelled us towards an optimal design solution, poised to deliver a remarkable user experience.

## 2.1 Design-Driven Innovation

2.1.1 Sketches (Hand-drawn)

Sketch – 01

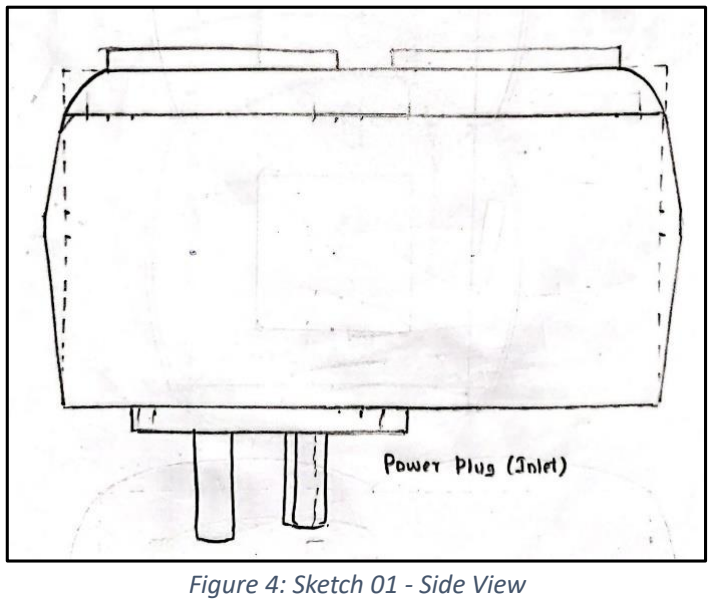
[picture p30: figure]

My initial design aimed to address the limitations of traditional multiplugs commonly used in our daily lives. Many of these multiplugs lack multiple outlets and a convenient power switch. So that we as a group chose this design featuring two power outlets, along with a shared power switch for simultaneous control. Furthermore, as the outlets were placed vertically, they are positioned in opposite directions to prevent any potential collision between connected plugs.

Figure 1: Sketch 01 - Top View | Figure 2: Sketch 01 - Bottom View
Figure 3: Sketch 01 - Front View | Figure 4: Sketch 01 - Side View

Sketch – 02

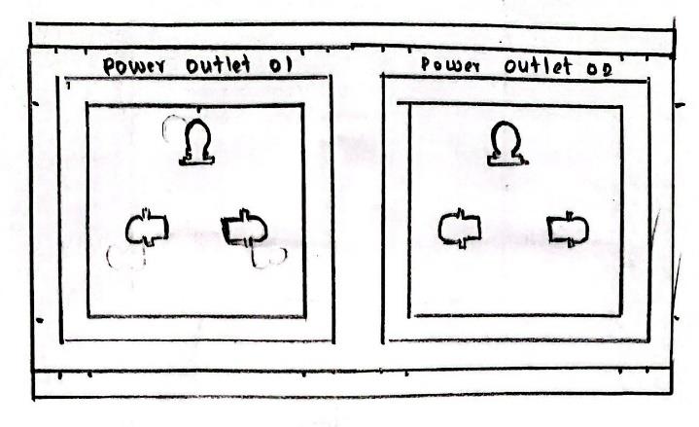
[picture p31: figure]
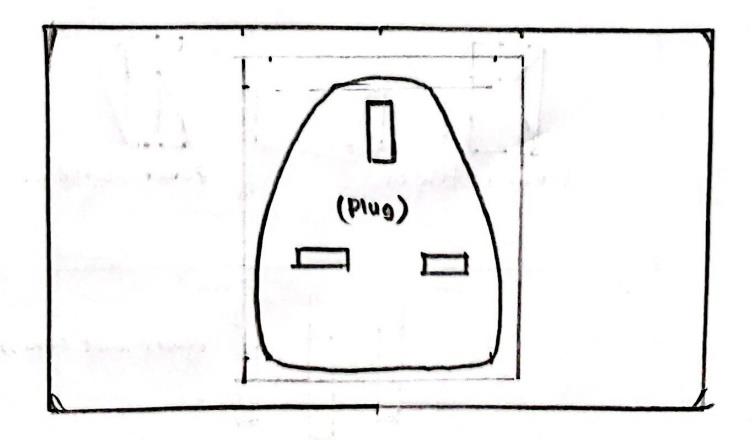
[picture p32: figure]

In the previous design, there’s a drawback where only one control switch was available to operate both power outlets simultaneously. To address this, separate power switches were introduced for each outlet in the revised design. Additionally, as the power outlets are now positioned horizontally, there is no need to arrange them in opposite directions. Consequently, both outlets are placed in an upright position.

A limitation of this design is that since the outlets are positioned horizontally, it may obstruct adjacent outlets on home or office walls, as they are typically oriented in a horizontal arrangement.

Figure 5: Sketch 02 - Top View | Figure 6: Sketch 02 - Side View
Figure 7: Sketch 02 - Front View | Figure 8: Sketch 02 – Bottom View

Sketch – 03

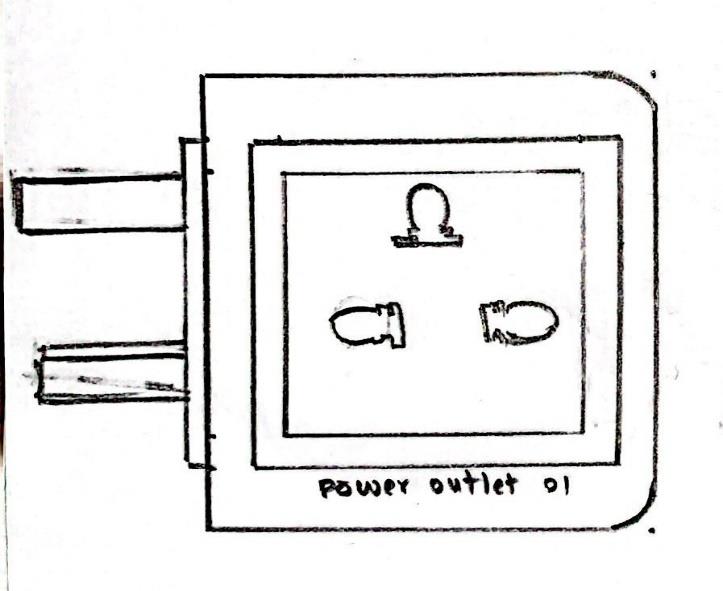
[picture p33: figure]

The previous two designs are relatively larger in size. To address this concern, a compact design was thought, which became the focus of the third sketch. Similar to the second sketch, this design also featured two separate power switches for the outlets. However, in order to achieve a more compact form, the rocker switches are replaced with button switches.

Additionally, the power outlets were positioned on both sides of the design in an upright orientation. While the compactness of the design was advantageous, it posed challenges in accommodating all the components and the PCB within the proposed design, serving as its sole drawback.

Figure 9: Sketch 03 - Front View | Figure 10: Sketch 03 - Side View (1)
Figure 11: Sketch 03 - Bottom View | Figure 12: Sketch 03 - Side View (2)

2.1.2 Block Diagrams

Block Diagram – 01

This is the initial block diagram that aligns closely with my original design concept. To ensure efficient power supply to the Wi-Fi module, a single module that directly converts the 230V AC input to 5V DC is used. This approach not only contributes to a compact PCB design but also facilitates the overall compactness of the product. Consequently, it becomes more convenient to power both the Wi-Fi module and the temperature sensor within the smart plug.

The BLYNK IoT platform is used because of its user-friendly nature and simplistic user interface. This choice ensures easy setup and enhances the marketability of the product. Additionally, BLYNK offers all the desired features and functionalities I had envisioned for the smart plug.

Block Diagram – 02

In the revised block diagram, an alternative approach was proposed, recommending the use of a transformer and regulator to convert AC voltage to DC voltage instead of a single module as previously suggested. However, this upgrade won’t be suitable as it would occupy more space, potentially resulting in a larger product size. This design has USB-C and USB-A outlets for direct device charging, eliminating the need for adapters.

Diagram 2: Block Diagram - 02

Block Diagram - 03

Diagram 3: Block Diagram - 03

In this approach, a Bluetooth module was used instead of a Wi-Fi module for remote control. With a Bluetooth module, the functionality would be limited to simply turning the plug on or off, without the ability to schedule ON/OFF times. This would require an additional mechanism for scheduling. Additionally, the proposed design included a single AC to DC converter module and retained the USB-A and USB-C charging outlets from previous design. In this approach, there would be no need for an IoT platform, as a mobile device with Bluetooth capability and the necessary applications would suffice.

## 2.2 User-centered design

To gather diverse user feedback and identify areas for improvement, surveys were conducted among university undergraduates and external individuals regarding the initial design. A questionnaire was developed, comprising the following set of questions:

1. How frequently do you use power outlets or multiplugs in your daily life?
2. What are the limitations or drawbacks you perceive with traditional power outlets or multiplugs?
3. Have you ever used a smart plug before? If yes, what were your experiences with it?
4. What devices or appliances do you think can be connected to power outlets that could benefit from smart plug functionality?
5. Are there any specific price points or budget considerations you would have for a smart plug?
6. What other features or improvements would you like to see in a smart plug?

A total of 10 completed questionnaires were collected within the designated two-hour period, and below is a summary of the results for each question.

1. Since the majority of respondents were university students, they frequently utilize power outlets and multiplugs to charge their laptops, mobile phones, and other accessories.
2. The primary limitations identified by the respondents regarding traditional power outlets were instances where they inadvertently connected devices without turning them on for an extended period, resulting in delayed charging. Similarly, they often forgot to turn off connected devices and left the area, leading to battery damage over time.
3. The majority of respondents had no prior experience using a smart plug, with only one participant having used one and expressing satisfaction with its enhanced efficiency compared to traditional power outlets.
4. Devices or appliances such as laptops, mobile phones, tablets, desk lamps, and portable speakers can benefit from smart plug functionality for convenient charging and power management. Other than that, devices, or appliances such as televisions, gaming consoles, home theater systems, air conditioners, and kitchen appliances like coffee makers and toaster ovens can benefit from smart plug functionality in a household setting.
5. The primary barrier preventing respondents from adopting smart plugs was the perceived high cost of these devices. They expressed a strong desire for smart plugs that are affordable and accessible to a wider range of users.
6. The respondents have provided various specifications, some of which are feasible for the current level of product development, while others may not be practical or not needed for a smart plug.

Selected specifications

The respondents have suggested several features that are practically feasible to implement in a smart plug.

- Including a power monitoring feature that enables users to monitor and manage their energy consumption through the IoT platform.
- Incorporating voice control functionality in addition to remote control capabilities through either a mobile or desktop application.
- Equipping the smart plug with USB-C and USB-A power outlets to facilitate device charging.
- Striving to offer the smart plug at an affordable price point while ensuring the highest possible product quality.

Rejected specifications.

While there are some noteworthy features suggested for a smart plug, not all of them are practically feasible or necessary for its functionality.

- Adding a camera to a smart plug may raise privacy concerns and be impractical for a power control-oriented device.
- Displaying a screen on a smart plug may raise costs and complexity without significant power control benefits.
- Advanced automation and machine learning algorithms may not be necessary for a smart plug, as its primary purpose is convenient power control rather than complex decision-making capabilities.

Following the design cycle outlined in the reference, we were able to develop the following design incorporating the additional features suggested by the respondents.

2.2.1 Sketches (Hand-drawn)

Sketch – 04


In this design, two individual button switches for separate control of the two outlets have been included. Additionally, there are two USB-A outlets and one USB-C outlet for convenient device charging without the need for an adapter. To ensure proper airflow and prevent overheating, air vents have been incorporated into the design.

No modifications to the enclosure are required to incorporate the remaining selected features from the respondents. These additions have been included in the following block diagram.

Figure 13: Sketch 04 - Side View | Figure 14: Sketch 04 - Front View
Figure 15: Sketch 04 - Top View | Figure 16: Sketch 04 - Bottom View

2.2.2 Block Diagrams

Block Diagram – 04

In addition to the initial block diagram (Block Diagram 01), the updated design includes the integration of USB charging modules and a temperature sensor. Furthermore, to meet the respondents' request for power monitoring, a current sensor has been incorporated. This sensor provides real-time current data to the ESP module, allowing for power calculation through appropriate coding.

The Wi-Fi module facilitates data transfer to the IoT platform, enabling users to monitor power usage and plan accordingly. Additionally, voice control functionality can be enabled using platforms such as Alexa or other voice assistants, in conjunction with the selected IoT platform.

## 2.3 Selection Matrix

This part introduces the selection matrix used to assess and prioritize the design options resulting from the design-driven innovation cycles. By incorporating inputs from the group members and gathering feedback from users, the selection matrix has been developed as a valuable tool for guiding the decision-making process towards the ultimate design of the smart plug. Through the careful consideration of various factors, the matrix offers insightful analysis and recommendations to ensure an informed and well-founded final design choice.

2.3.1 For Sketches
- Functionality:
- Does the design fulfill the functional requirements of the smart plug enclosure? Does it offer sufficient room for components and ensure proper ventilation?
- Aesthetics:
- Is the design visually pleasing? Does it match the desired aesthetic of the smart plug?
- Ergonomics:
- Does the design take into account user ergonomics? Is it user-friendly and comfortable to handle, carry, and interact with?
- Size and Portability:
- Is the design of the enclosure suitable for its intended purpose in terms of size? Does it offer a compact and easily portable solution if needed?
- Manufacturing Feasibility:
- Is the design capable of being manufactured effectively? Does it consider the ease of assembly and the overall manufacturing process?
- Component Accessibility:
- Does the design facilitate convenient access to essential components, including buttons, ports, and displays?
- Durability:
- Is the design resilient enough to withstand regular usage and various environmental conditions? Does it provide sufficient protection for the internal components?
- Cost-Effectiveness:
- Does the design offer a cost-efficient solution considering factors such as material selection, manufacturing processes, and assembly methods?
- Innovation:
- Does the design incorporate distinctive or novel elements that differentiate it from existing enclosures available in the market?
- Environmental Impact:
- Does the design consider environmental considerations, including the utilization of sustainable materials and energy-efficient features?

Based on the assessment of the above10 criteria, all four designs have been evaluated on a scale of 1 to 10.

| Criteria | Sketch - 01 | Sketch - 02 | Sketch - 03 | Sketch - 04
1. | Functionality | 8 | 8 | 6 | 8
2. | Aesthetics | 7 | 7 | 6 | 8
3. | Ergonomics | 6 | 6 | 7 | 7
4. | Size and Portability | 6 | 6 | 7 | 7
5. | Manufacturing Feasibility | 7 | 7 | 6 | 7
6. | Component Accessibility | 6 | 7 | 6 | 7
7. | Durability | 7 | 7 | 7 | 7
8. | Cost-Effectiveness | 7 | 7 | 7 | 7
9. | Innovation | 5 | 5 | 4 | 6
10. | Environmental Impact | 6 | 6 | 6 | 6
Total (out of 100) | | 65 | 62 | 66 | 70

Based on the evaluation conducted using the selection matrix, Sketch-04 emerged as the most suitable design among the four sketches. This design incorporated inputs from the Design-driven innovation approach and User-centered design approach, making it the preferred choice.

2.3.2 For Block Diagram
- Functionality:
- Does the diagram effectively represent all the key functions and features of the "Smart plug" circuit?
- Clarity:
- Does the diagram offer clarity and simplicity, enabling easy comprehension and visual representation of the circuit's functioning?
- Connectivity:
- Does the diagram accurately illustrate the connections and interfaces between the various functional blocks?
- Modularity:
- Does the circuit design facilitate the integration and troubleshooting of individual blocks through a modular approach?
- Compatibility:
- Does the circuit design align with the necessary input/output devices and communication protocols, ensuring seamless compatibility?

- Expandability:
- Does the circuit diagram facilitate effortless incorporation of new features or functionalities in the future?
- Cost-Efficiency:
- Does the circuit diagram consider cost-effective component selection and manufacturing considerations?
- Size and Form:
- Does the circuit diagram take into consideration the size and form requirements for seamless integration into the desired enclosure or device?
- Component Accessibility:
- Are the components utilized in the circuit diagram easily accessible and readily available for procurement?
- Regulatory Compliance:
- Does the circuit design adhere to applicable industry standards and regulations?

Based on the assessment of the above10 criteria, all four designs have been evaluated on a scale of 1 to 10.

| Criteria | Block - 01 | Block - 02 | Block - 03 | Block - 04
1. | Functionality | 7 | 6 | 5 | 8
2. | Clarity | 7 | 7 | 7 | 7
3. | Connectivity | 7 | 7 | 7 | 7
4. | Modularity | 7 | 7 | 6 | 7
5. | Compatibility | 7 | 6 | 6 | 7
6. | Expandability | 6 | 6 | 4 | 7
7. | Cost Efficiency | 7 | 6 | 8 | 7
8. | Size and Form | 7 | 5 | 7 | 7
9. | Component Accessibility | 6 | 6 | 5 | 6
10. | Regulatory Compliance | 6 | 6 | 6 | 6
Total (out of 100) | | 67 | 62 | 61 | 69

Based on the evaluation conducted using the selection matrix, Block Diagram - 04 emerged as the most suitable design among the four sketches. This design incorporated inputs from the Design-driven innovation approach and User-centered design approach, making it the preferred choice.

## 3. Preliminary Design

During the preliminary design phase, a meticulous approach was undertaken after the careful selection of the enclosure sketch and block diagram for the product. The sketch was meticulously transformed into a comprehensive SolidWorks design, while the block diagram was skillfully translated into a detailed circuit schematic.

In the early stages of this design phase, the initial SolidWorks design and schematic design were crafted without the advantage of prior knowledge concerning established professional design processes. However, recognizing the significance of following industry best practices, a transformative shift occurred after incorporating insights from Lecture contents. These invaluable inputs served as a catalyst for enhancing the design process, ensuring adherence to proper and standardized methodologies.

The inclusion of the Lecture contents proved instrumental in refining and optimizing the SolidWorks design and schematic design. Leveraging newfound understanding, the designs were meticulously revised, incorporating the appropriate professional design processes. This conscientious approach not only enhanced the overall quality of the designs but also facilitated seamless integration with subsequent stages of the project.

By embracing a more informed and refined design process, the preliminary designs evolved into robust and well-structured representations. This newfound adherence to professional design practices instills confidence that the subsequent phases of the project will be executed with greater efficiency and precision.


Figure 17: Final Product

## 3.1 Implemented Design


3.1.1 Sketches

Figure 18: Sketches: Initial Design


Figure 19: SolidWorks Design: Initial (1 of 3)

3.1.2 SolidWorks Designs


Figure 20: Solid

Works Design: Initial (2 of 3)


Figure 21: SolidWorks Design: Initial (3 of 3)

3.1.3 Block Diagram


The smart plug was initially developed with a conventional design, consisting of two power outlets and the capability to be wirelessly controlled through a Wi-Fi connection.

The mentioned block diagram outlines the various features and specifications of this smart plug.

These are the features that the IoT platform will provide,

- There will be two distinct switch controls provided to manage the individual outlets.
- The platform allows for the scheduling of ON/OFF times for the smart plug.
- Utilizing the temperature data obtained from the sensor, the smart plug will incorporate an automation feature that automatically switches off when the temperature surpasses the upper threshold level. Likewise, it turns on the plug automatically once the temperature drops below the lower threshold level.

Diagram 5: Block Diagram (Initial Design)


3.1.4 Schematic Design

Figure 22: Initial Schematic

3.2 Problems identified after considering the course content.

- Mass production:
- When it comes to producing a large quantity of units, 3D printing is not the most efficient approach. In contrast, molding enables quicker and more cost-effective production of identical components. However, my previous design cannot undergo the molding process, indicating that it might have features or geometries that are incompatible with molding.
- Draft angles:
- In the process of molding, draft angles hold significant importance as they facilitate the effortless extraction of the molded component from the mold. Insufficient draft angles can lead to part entrapment or subpar surface finishing. To ensure seamless production and the creation of high-quality molded parts, it is crucial to integrate appropriate draft angles into the design. Unfortunately, I neglected to consider the importance of draft angles in my previous design.
- Visual aesthetics:
- The visual appeal of a product plays a vital role in captivating customers and creating a desirable product. While functionality remains significant, it is equally important to consider the overall visual appeal of the design. Elements such as sleek lines, well-balanced proportions, and an aesthetically pleasing color palette should be considered to enhance the attractiveness of the product. Regrettably, I failed to consider this aspect in my previous design.
- Screw positioning:
- For improved market appeal and user satisfaction, it is advisable to conceal screws from direct view. Placing screws on the underside or within the enclosure contributes to a neater and more polished aesthetic. However, in my enclosure design, I positioned the screws on the top surface, which detracted from its overall cleanliness and professional appearance.
- Surface modeling:
- Surface modeling encompasses the creation of sleek and visually pleasing curves, chamfers, and fillets on the outer surfaces of the enclosure. This method is frequently employed to achieve a sophisticated and premium aesthetic. Unfortunately, I did not incorporate this approach in my previous design, resulting in a lack of professional and refined appearance.

- Enclosure assembly:
- To eliminate the reliance on adhesives such as hot glue, it is crucial to achieve seamless integration of the enclosure components, eliminating the necessity for supplementary fixes. This necessitates careful scrutiny of details and meticulous dimensional planning. However, I made certain errors in this aspect as well.
- Hand-drawn Sketches
- Neglecting the recommended procedure, I deviated from the ideal approach for enclosure design by not commencing with hand-drawn sketches.

I have implemented the essential enhancements in my design to fulfill the requirements. I have commenced the enclosure design process with hand-drawn sketches. The design now possesses compatibility for molding, exhibits aesthetic appeal, integrates suitable draft angles, conceals screws, employs surface modeling techniques, and guarantees secure enclosure assembly without the necessity of adhesives.

3.3 Problems/Improvements identified/proposed by group members.

3.3.1 Problems
- Insufficient presence of visually pleasing curves:
- The initial design lacked the inclusion of attractive curves. To rectify this, my group members proposed integrating a greater number of curves into the enclosure design, thereby enhancing its overall visual appeal.
- Limitations in wiring space:
- The previous design faced constraints in terms of available space, posing challenges in accommodating appropriate wiring within the product. To overcome this issue, my teammates recommended making design modifications that would allow for sufficient space to facilitate proper wiring connections.

3.3.2 Improvements
- Separate power switches
- In the initial design, a single power switch was implemented to manually control both power outlets simultaneously. However, based on the recommendations of my group members, it was advised to adopt a revised approach by incorporating two separate power switches, each dedicated to controlling an individual power outlet.

3.4 Problems/Improvements identified/proposed by users.
Based on user feedback obtained through a comprehensive user survey, I identified various issues in my design and schematic. Consequently, I made necessary modifications and implemented improvements as suggested by the users.

3.4.1 Problems
- No USB outlets for direct charging
- In the initial design, the absence of USB outlets for direct device charging without a power adapter was a notable concern raised by several users. As a result, there was a collective request for the inclusion of both USB-C and USB-A outlets to address this issue.

3.4.2 Improvements
- Power monitoring feature
- Based on user feedback, there was a strong desire for a power monitoring feature within the mobile application. This functionality would enable users to track their power consumption, empowering them to effectively monitor and plan their activities accordingly.
- Voice Control feature
- A subset of users indicated a preference for the inclusion of voice control functionality alongside the existing remote-control capabilities through the mobile application. This enhancement would significantly enhance user convenience and simplify their daily lives.

I have diligently implemented all the recommended improvements provided by both my group members and the users. I have exerted considerable effort to address the design issues. To incorporate USB outlets, I utilized a power bank module, while integrating voice control capabilities through various platforms. Additionally, I incorporated a current sensor module to enable power monitoring, enhancing the IoT platform to display this information to users. Furthermore, I have made significant enhancements to the enclosure design, ensuring adequate spacing for wiring requirements.

## 3.5 Improved Design


3.5.1 Sketches

Figure 23: Sketches (Improved Design)


Figure 24: SolidWorks Design: Improved (1 of 2)

3.5.2 SolidWorks Designs


Figure 25: SolidWorks Design: Improved (2 of 2)


Figure 26: Core and Cavity Model (Page 1 of 2)

3.5.3 Mold Design – Top Lid (Injection molding)


Figure 27: Core and Cavity Model (Page 2 of 2)


3.5.3 Block Diagram

To accommodate the USB outlets in the schematic design, I incorporated the connector (J4). Additionally, to facilitate individual control of the two outlets, I introduced the rocker switches (SW2 and SW3) into the design.

Diagram 6: Block Diagram (Improved)


3.5.4 Schematic Design

Figure 28: Improved Schematic

## 4. Detailed Design

During the detailed design phase, significant progress was made to transform the improved schematic into a meticulously crafted PCB design. Careful consideration was given to selecting the appropriate components required for constructing the product. Various criteria such as availability and suitability were considered to ensure optimal choices.

The design of the product revolved around the ESP8266 NodeMCU module, which served as a central component. Leveraging the versatility and capabilities of this module, source code was programmed using the Arduino IDE, enabling efficient and reliable functionality.

To materialize the design, a robust supply chain was established, and meticulous efforts were made to import the necessary components from reputable suppliers. Simultaneously, the designed PCB was printed overseas and subsequently imported to ensure high-quality production standards.

With all components and the PCB in hand, the next step involved the creation of a prototype, which was subject to thorough testing. This critical phase allowed for the identification of any potential design flaws, ensuring that necessary adjustments and refinements could be made prior to the final production stage.

While the ultimate plan involved manufacturing the enclosure through Injection molding, the prototype for the enclosure was initially created using 3D printing. This agile approach provided a tangible representation of the envisioned design, allowing for additional testing and validation.

The detailed design phase was characterized by meticulous attention to detail, adherence to professional standards, and the pursuit of excellence. The culmination of these efforts brought us closer to the realization of a functional and robust product, poised to meet the needs and expectations of its intended users.

## 4.1 PCB Design


Figure 26: Top Layer

Figure 27: Bottom Layer


## 4.2 Source Code

Arduino Code: GitHub Link (https://github.com/ChristClenson/EN2160_Electronic_Design_Realization/tree/main)

Figure 28: PCB

Figure 29: PCB (3D View)

## 4.3 Bill of Materials (BOM)

No. | Component | Model | Unit Price (LKR) | Quantity | Total Price (LKR)
1. | Development Board | ESP8266 NodeMCU | 1000.00 | 1 | 1000.00
2. | 230V AC to 5V DC converter | HI-LINK HLK-5M05 | 890.00 | 1 | 890.00
3. | 5V Relay | Songle SRD-5VDC | 120.00 | 2 | 240.00
4. | Temperature Sensor | MSKSEMI DS18B20 | 170.00 | 1 | 170.00
5. | Transistor | LGE BC547B | 10.00 | 2 | 20.00
6. | Varistor | RUILON 10D561K | 20.00 | 1 | 20.00
7. | Diode | JUXING 1N4007 | 10.00 | 2 | 20.00
8. | Button Switch | Tactile Push Button | 20.00 | 1 | 20.00
9. | Resistor | 1KΩ | 2.00 | 2 | 4.00
10. | Resistor | 220 Ω | 2.00 | 1 | 2.00
11. | Resistor | 100 Ω | 2.00 | 2 | 4.00
12. | LED | RED | 10.00 | 2 | 20.00
13. | Screw Terminal Block | 2 Pin | 30.00 | 3 | 90.00
Total Amount (Components only) | | | | | 2500.00

The components have all been imported from abroad, and the total cost of shipping, including
VAT and other taxes, amounts to LKR 2500.00.

Total Components Cost = LKR 5000.00

PCB Cost:

PCB was printed in JLC PCB, China.

PCB Printing Cost = LKR 1500.00

PCB Shipping Cost = LKR 2000.00

Total PCB Cost = LKR 3500.00

Enclosure Cost:

Enclosure was printed using 3D printing in Sri Lanka.

Printing Cost = LKR 4500.00

Shipping Cost = LKR 500.00

Total Enclosure Cost = LKR 5000.00

Total Cost:

Components = LKR 5000.00

PCB = LKR 3500.00

Enclosure = LKR 5000.00

Total Cost = LKR 13500.00

## 4.4 Supply Chain

No. | Component | Supplier
1. | Development Board (https://jdp-ic.en.made-in-china.com/product/MwZAjyqEQoVI/China-Nodemcu-Electronic-Development-Board-Esp8266-Wireless-WiFi-Module.html) | Shenzhen Jin Da Peng Technologies, China
2. 230V AC to 5V DC converter (https://www.lcsc.com/product-detail/Power-Modules_HI-LINK-HLK-5M05_C209907.html)
3. 5V Relay (https://www.lcsc.com/product-detail/Power-Relays_Ningbo-span-style-background-color-ff0-Songle-span-span-style-background-color-ff0-Relay-span-SRD-5VDC-SL-A_C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)
4. Temperature Sensor (https://www.lcsc.com/product-detail/Temperature-Sensors_MSKSEMI-DS18B20_C5379069.html)
5. Transistor (https://www.lcsc.com/product-detail/Bipolar-Transistors-BJT_LGE-BC547B_C713613.html)
6. Varistor (https://www.lcsc.com/product-detail/Varistors_RUILON-Shenzhen-Ruilongyuan-Elec-10D561K_C233178.html)
7. Diode (https://www.lcsc.com/product-detail/Diodes-General-Purpose_JUXING-1N4007_C3011149.html)
8. Button Switch (https://www.lcsc.com/product-detail/span-style-background-color-ff0-Button-span-Signal-Lamp-Main-span-style-background-color-ff0-Switch-span_BOCHEN-Chengdu-Gu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)
9. Resistor (https://www.lcsc.com/products/Through-Hole-Resistors_11239.html)
10. LED (https://www.lcsc.com/product-detail/Light-Emitting-Diodes-LED_Everlight-Elec-204-10SDRD-S530-A3-L_C84774.html)
11. Screw Terminal Block (https://www.lcsc.com/product-detail/span-style-background-color-ff0-Screw-span-span-style-background-color-ff0-terminal-span_Cixi-Kefa-Elec-KF331-5-0-2P_C6392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)

LCSC Electronics, China

## 5. Summary and Conclusion

During the initial stages of development, I successfully implemented several exciting features for the smart plug, as mentioned in the introduction. However, due to certain technical challenges, I couldn't achieve all the planned and recommended features from colleagues and users. Nevertheless, I am committed to continuously improving our product, and here are some future upgrades that we are considering:

Voice Control:

I understand the importance of voice control for seamless user experience. Therefore, integrating the smart plug with popular voice assistants like Alexa and Google Voice Assistant will be a much-needed upgrade. With this upgrade, users will be able to control the plug's functionalities using simple voice commands.

Enhanced Charging Options:

In response to user feedback, incorporating both USB-C and USB-A outlets into the smart plug will be a valuable addition. This addition will enable users to charge a wider range of devices simultaneously, catering to various charging needs.

Separate Power Switches:

To offer greater manual control and convenience, adding individual power switches for each outlet on the smart plug. This way, users can turn on/off specific devices connected to the plug without affecting others.

Power Monitoring Features:

Recognizing the growing demand for energy efficiency, developing power monitoring capabilities for the smart plug will be more appropriate. This feature will allow users to track energy consumption of connected devices and gain insights into their power usage, promoting responsible energy practices.

I appreciate the valuable input from my colleagues and users. While I couldn't implement all the suggested features initially, I am committed to making the smart plug even smarter and more versatile with these exciting upgrades in the pipeline.

## 6. Annexures

## 7. Bibliography

1. Inclusive Design Toolkit – Cambridge University (http://www.inclusivedesigntoolkit.com/GS_overview/overview.html)
Figure 1: Final Product (Side View) | Figure 35: Smartie, PCB and Blynk mobile App
Figure 36: Prototype Testing | Figure 2: Final Product (Front View)

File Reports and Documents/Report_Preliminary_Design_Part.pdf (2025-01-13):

## University of Moratuwa

## Department of Electronic and Telecommunication Engineering


## EN2160: Electronic Design Realization

### Report - Preliminary Design Part

### Index No: 200396U

Name: Miranda C.M.C.C.

### Product: Smart Plug

## Implemented Design


Sketches

Figure 1: Sketches: Initial Design


Figure 2: Solidworks Design: Initial (1 of 3)

Solidworks Designs


Figure 3: Solidwork Design: Initial (2 of 3)


Figure 4: Solidworks Design: Initial (3 of 3)

Block Diagram


The smart plug was initially developed with a conventional design, consisting of two power outlets and the capability to be wirelessly controlled through a Wi-Fi connection.

The mentioned block diagram outlines the various features and specifications of this smart plug.

These are the features that the IoT platform will provide,

- There will be two distinct switch controls provided to manage the individual outlets.
- The platform allows for the scheduling of ON/OFF times for the smart plug.
- Utilizing the temperature data obtained from the sensor, the smart plug will incorporate an automation feature that automatically switches off when the temperature surpasses the upper threshold level. Likewise, it turns on the plug automatically once the temperature drops below the lower threshold level.

Figure 5: Block Diagram (Initial Design)

# SRD-05VDC-SL-C K2

# 1N4007 K ¹ A 2 D2


Problems identified after considering the course content.

- Mass production:
- When it comes to producing a large quantity of units, 3D printing is not the most efficient approach. In contrast, molding enables quicker and more cost-effective production of identical components. However, my previous design cannot undergo the molding process, indicating that it might have features or geometries that are incompatible with molding.
- Draft angles:
- In the process of molding, draft angles hold significant importance as they facilitate the effortless extraction of the molded component from the mold. Insufficient draft angles can lead to part entrapment or subpar surface finishing. To ensure seamless production and the creation of high-quality molded parts, it is crucial to integrate appropriate draft angles into the design. Unfortunately, I neglected to consider the importance of draft angles in my previous design.
- Visual aesthetics:
- The visual appeal of a product plays a vital role in captivating customers and creating a desirable product. While functionality remains significant, it is equally important to consider the overall visual appeal of the design. Elements such as sleek lines, well-balanced proportions, and an aesthetically pleasing color palette should be considered to enhance the attractiveness of the product. Regrettably, I failed to consider this aspect in my previous design.
- Screw positioning:
- For improved market appeal and user satisfaction, it is advisable to conceal screws from direct view. Placing screws on the underside or within the enclosure contributes to a neater and more polished aesthetic. However, in my enclosure design, I positioned the screws on the top surface, which detracted from its overall cleanliness and professional appearance.
- Surface modeling:
- Surface modeling encompasses the creation of sleek and visually pleasing curves, chamfers, and fillets on the outer surfaces of the enclosure. This method is frequently employed to achieve a sophisticated and premium aesthetic. Unfortunately, I did not incorporate this approach in my previous design, resulting in a lack of professional and refined appearance.

- Enclosure assembly:
- To eliminate the reliance on adhesives such as hot glue, it is crucial to achieve seamless integration of the enclosure components, eliminating the necessity for supplementary fixes. This necessitates careful scrutiny of details and meticulous dimensional planning. However, I made certain errors in this aspect as well.
- Hand-drawn Sketches
- Neglecting the recommended procedure, I deviated from the ideal approach for enclosure design by not commencing with hand-drawn sketches.

I have implemented the essential enhancements in my design to fulfill the requirements. I have commenced the enclosure design process with hand-drawn sketches. The design now possesses compatibility for molding, exhibits aesthetic appeal, integrates suitable draft angles, conceals screws, employs surface modeling techniques, and guarantees secure enclosure assembly without the necessity of adhesives.

Problems/Improvements identified/proposed by members of group.

Problems
- Insufficient presence of visually pleasing curves:
- The initial design lacked the inclusion of attractive curves. To rectify this, my group members proposed integrating a greater number of curves into the enclosure design, thereby enhancing its overall visual appeal.
- Limitations in wiring space:
- The previous design faced constraints in terms of available space, posing challenges in accommodating appropriate wiring within the product. To overcome this issue, my teammates recommended making design modifications that would allow for sufficient space to facilitate proper wiring connections.

Improvements
- Separate power switches
- In the initial design, a single power switch was implemented to manually control both power outlets simultaneously. However, based on the recommendations of my group members, it was advised to adopt a revised approach by incorporating two separate power switches, each dedicated to controlling an individual power outlet.

Problems/Improvements identified/proposed by users.
Based on user feedback obtained through a comprehensive user survey, I identified various issues in my design and schematic. Consequently, I made necessary modifications and implemented improvements as suggested by the users.

Problems
- No USB outlets for direct charging
- In the initial design, the absence of USB outlets for direct device charging without a power adapter was a notable concern raised by several users. As a result, there was a collective request for the inclusion of both USB-C and USB-A outlets to address this issue.

Improvements
- Power monitoring feature
- Based on user feedback, there was a strong desire for a power monitoring feature within the mobile application. This functionality would enable users to track their power consumption, empowering them to effectively monitor and plan their activities accordingly.
- Voice Control feature
- A subset of users indicated a preference for the inclusion of voice control functionality alongside the existing remote-control capabilities through the mobile application. This enhancement would significantly enhance user convenience and simplify their daily lives.

I have diligently implemented all the recommended improvements provided by both my group members and the users. I have exerted considerable effort to address the design issues. To incorporate USB outlets, I utilized a power bank module, while integrating voice control capabilities through various platforms. Additionally, I incorporated a current sensor module to enable power monitoring, enhancing the IoT platform to display this information to users. Furthermore, I have made significant enhancements to the enclosure design, ensuring adequate spacing for wiring requirements.

## Improved Design


Sketches

Figure 6: Sketches (Improved Design)


Figure 7: Solidworks Design: Improved (1 of 2)

Solidworks Designs


Figure 8: Solidworks Design: Improved (2 of 2)


Block Diagram

Figure 9: Block Diagram (Improved)

To accommodate the USB outlets in the schematic design, I incorporated the connector (J4). Additionally, to facilitate individual control of the two outlets, I introduced the rocker switches (SW2 and SW3) into the design.


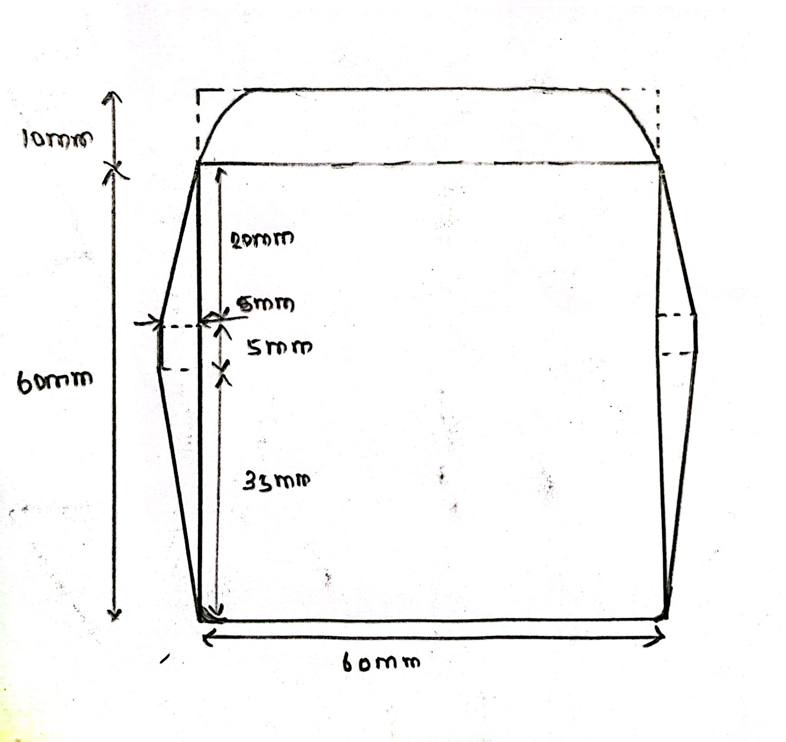
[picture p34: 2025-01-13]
Images/Core and Cavity/Front_Sketch.jpg

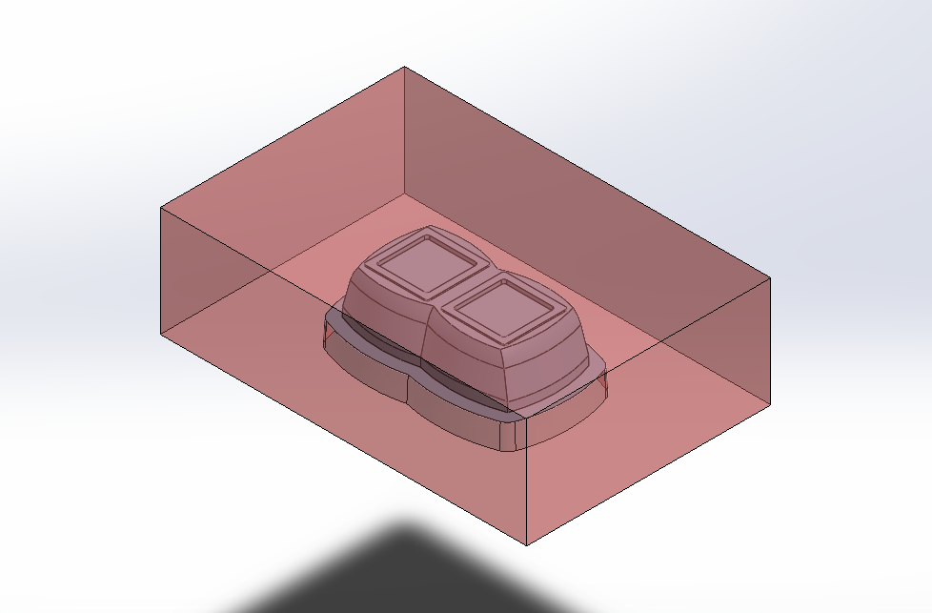
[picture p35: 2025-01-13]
Images/Core and Cavity/Cavity_Isomteric.png

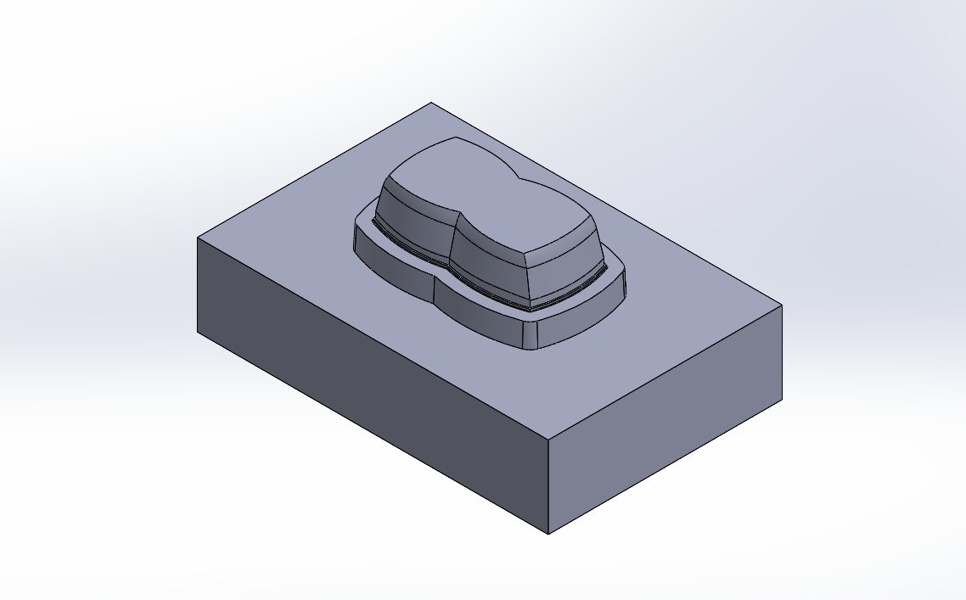
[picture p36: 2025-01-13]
Images/Core and Cavity/Core_Isometric_Final.png

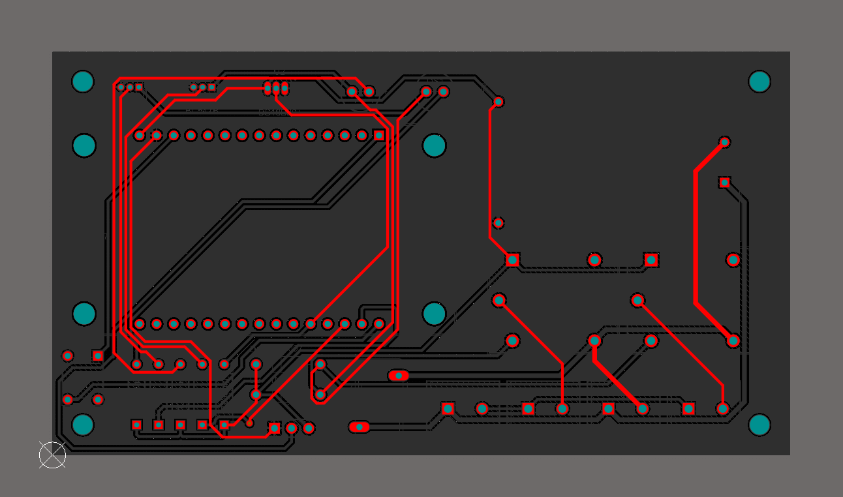
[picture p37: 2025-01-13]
Images/PCB/Top Layer.png

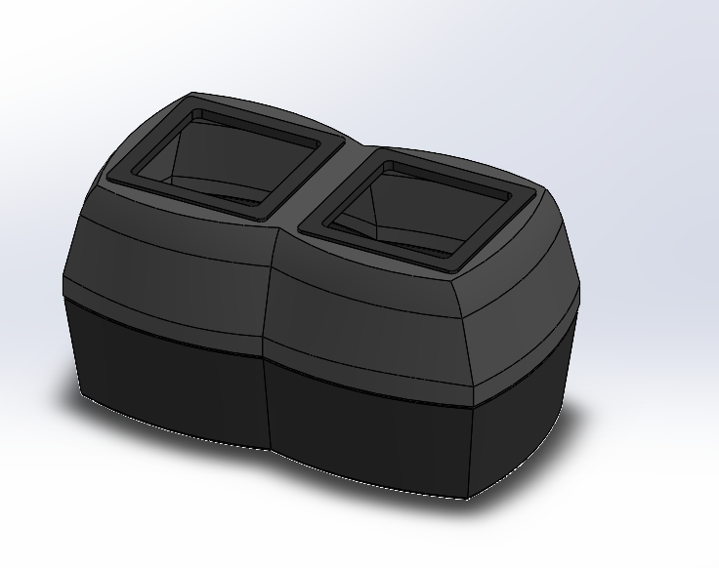
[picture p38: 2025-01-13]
Images/Core and Cavity/Enclosure_Trimetric.png

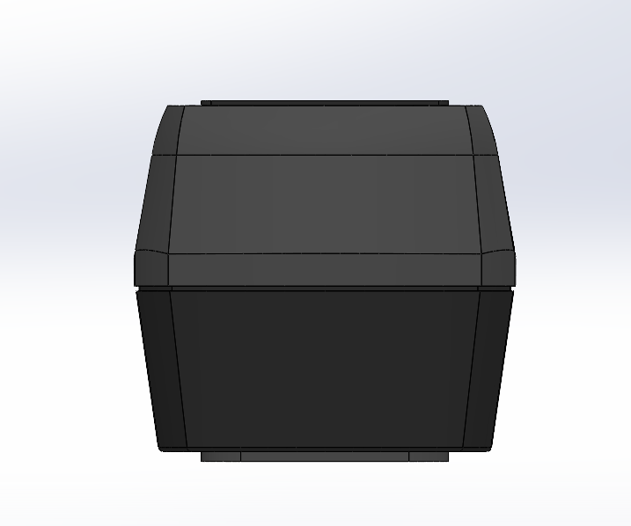
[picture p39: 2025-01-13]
Images/Core and Cavity/Enclosure_Front.png

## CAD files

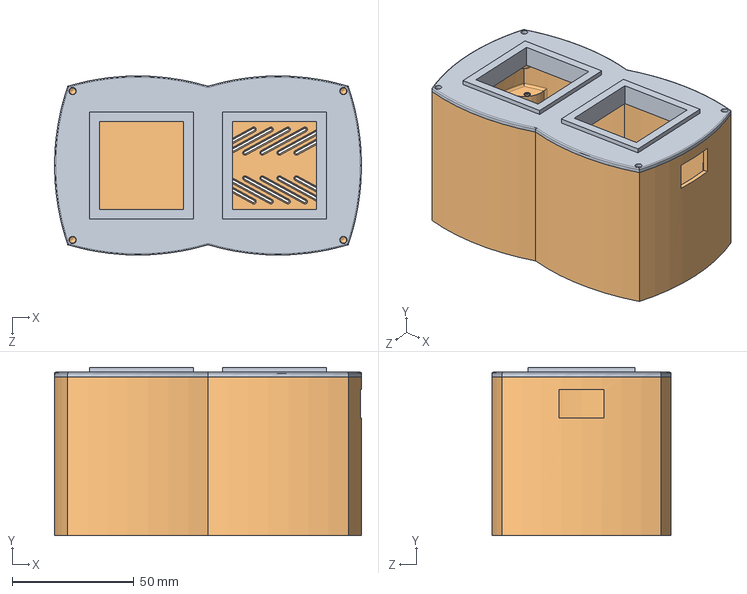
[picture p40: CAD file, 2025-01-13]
SolidWorks Files/Product Design/Assembled_Enclosure.SLDASM
125.9 x 69.0 x 73.4 mm

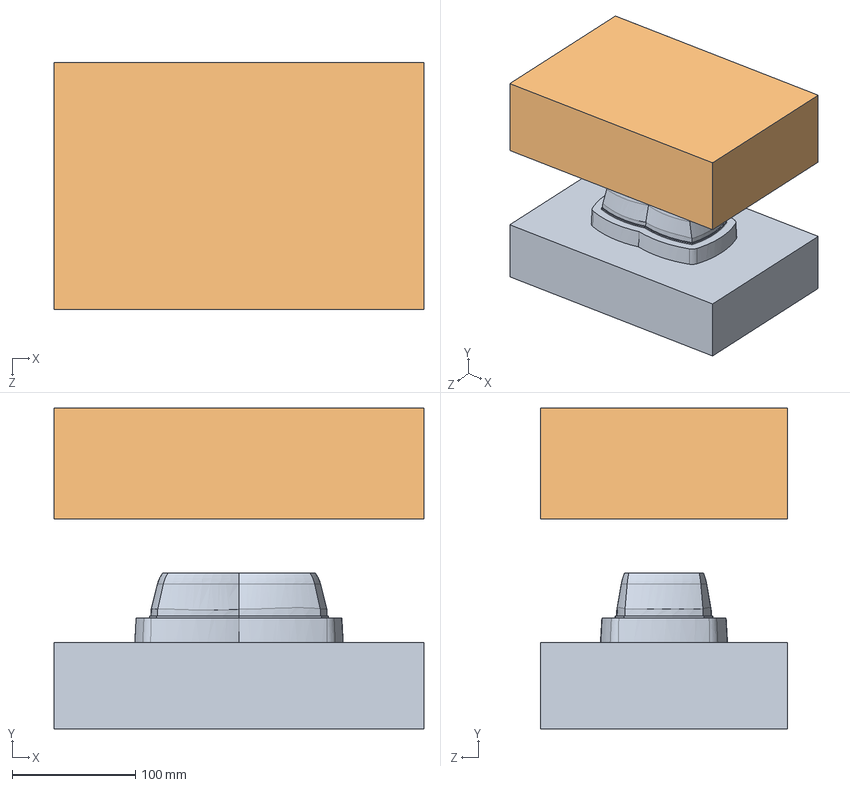
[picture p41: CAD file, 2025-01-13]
SolidWorks Files/Core and Cavity Designs/Core_And_Cavity.SLDASM
300.0 x 260.0 x 200.0 mm
Core
Cavity

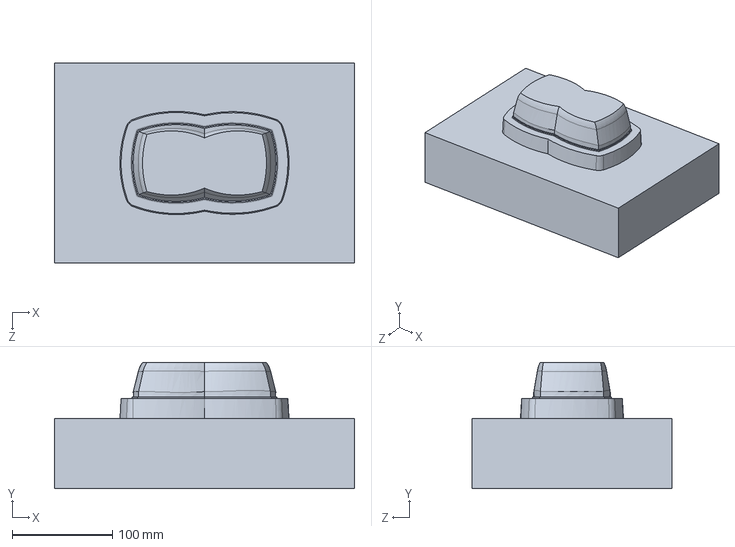
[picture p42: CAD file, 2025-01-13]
SolidWorks Files/Core and Cavity Designs/Core.SLDPRT
300.0 x 126.2 x 200.0 mm

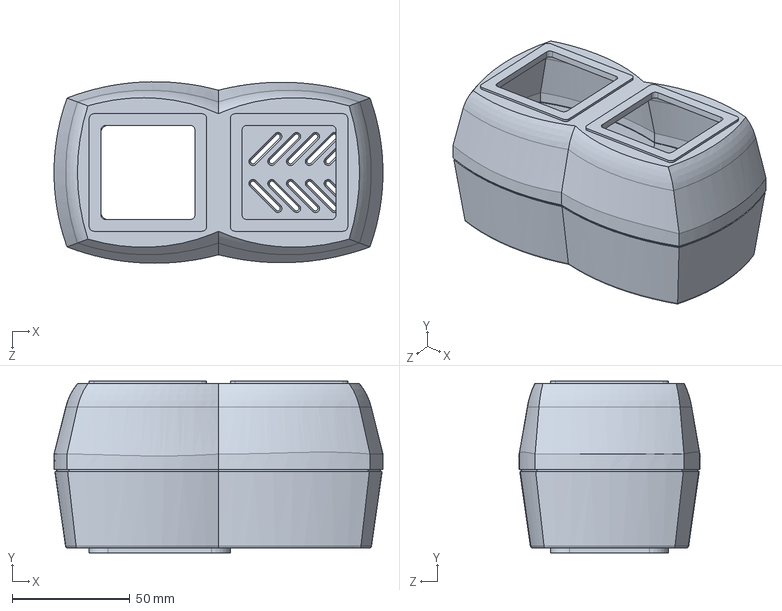
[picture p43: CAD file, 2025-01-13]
SolidWorks Files/Core and Cavity Designs/Enclosure.SLDPRT
140.0 x 73.0 x 77.2 mm

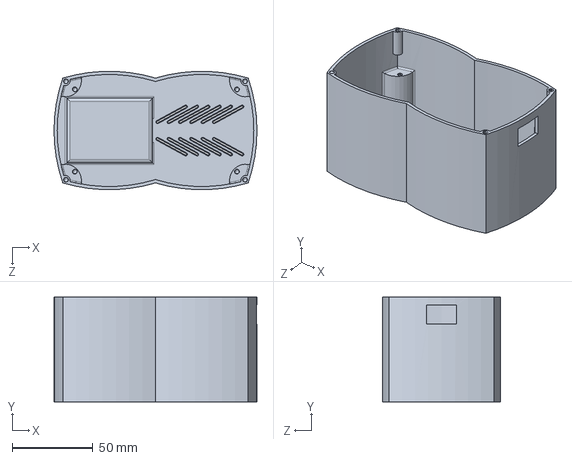
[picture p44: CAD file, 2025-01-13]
SolidWorks Files/Product Design/Bottom_Case.SLDPRT
125.9 x 65.0 x 73.3 mm

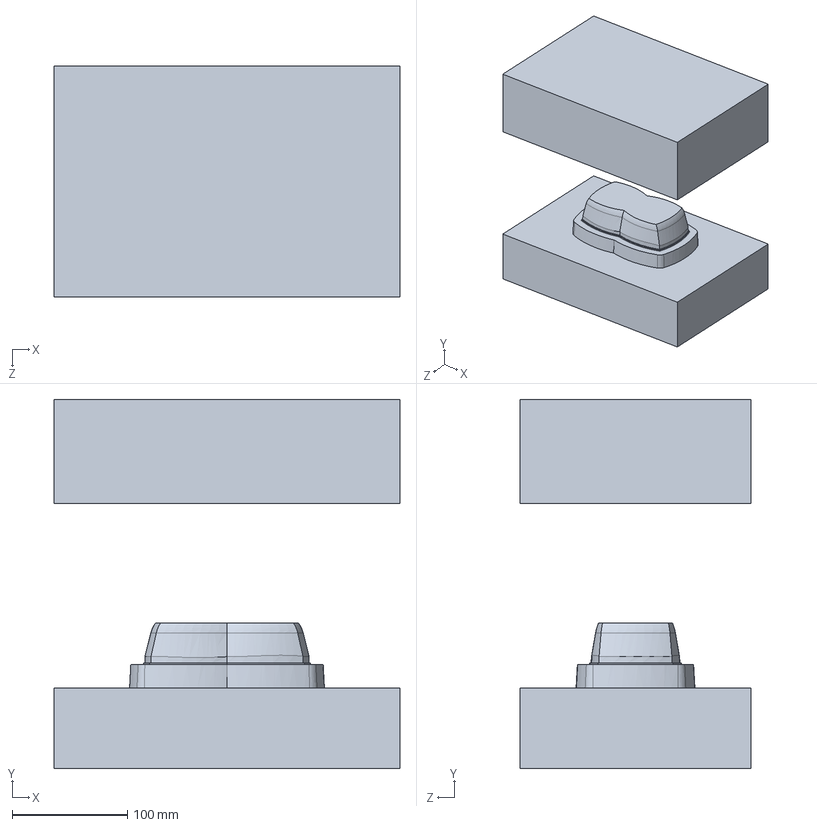
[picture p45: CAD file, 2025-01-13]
SolidWorks Files/Core and Cavity Designs/C&C_Design.SLDPRT
300.0 x 320.0 x 200.0 mm

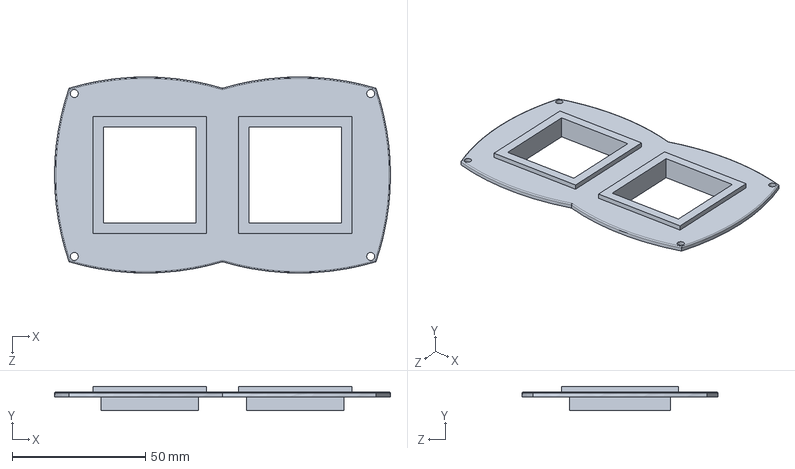
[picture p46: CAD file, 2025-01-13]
SolidWorks Files/Product Design/Top_Lid.SLDPRT
125.9 x 9.00 x 73.4 mm

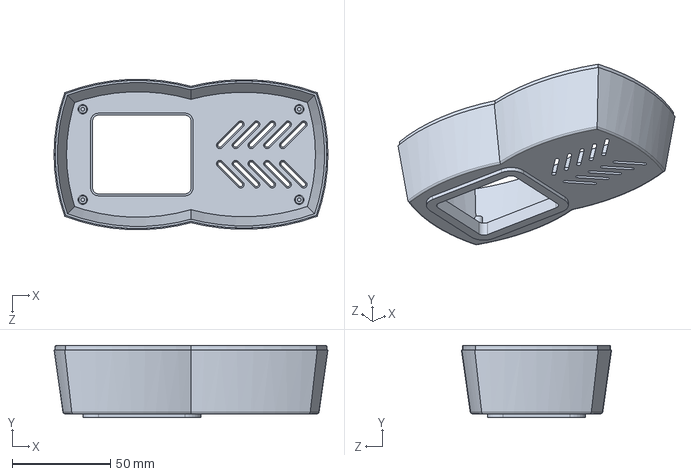
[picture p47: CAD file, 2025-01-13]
SolidWorks Files/Core and Cavity Designs/bottom.SLDPRT
139.2 x 36.8 x 76.4 mm

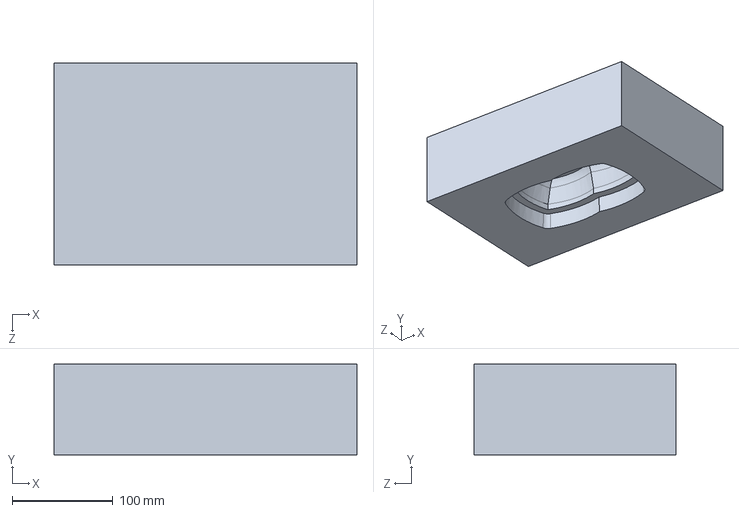
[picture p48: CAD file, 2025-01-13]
SolidWorks Files/Core and Cavity Designs/Cavity.SLDPRT
300.0 x 90.0 x 200.0 mm

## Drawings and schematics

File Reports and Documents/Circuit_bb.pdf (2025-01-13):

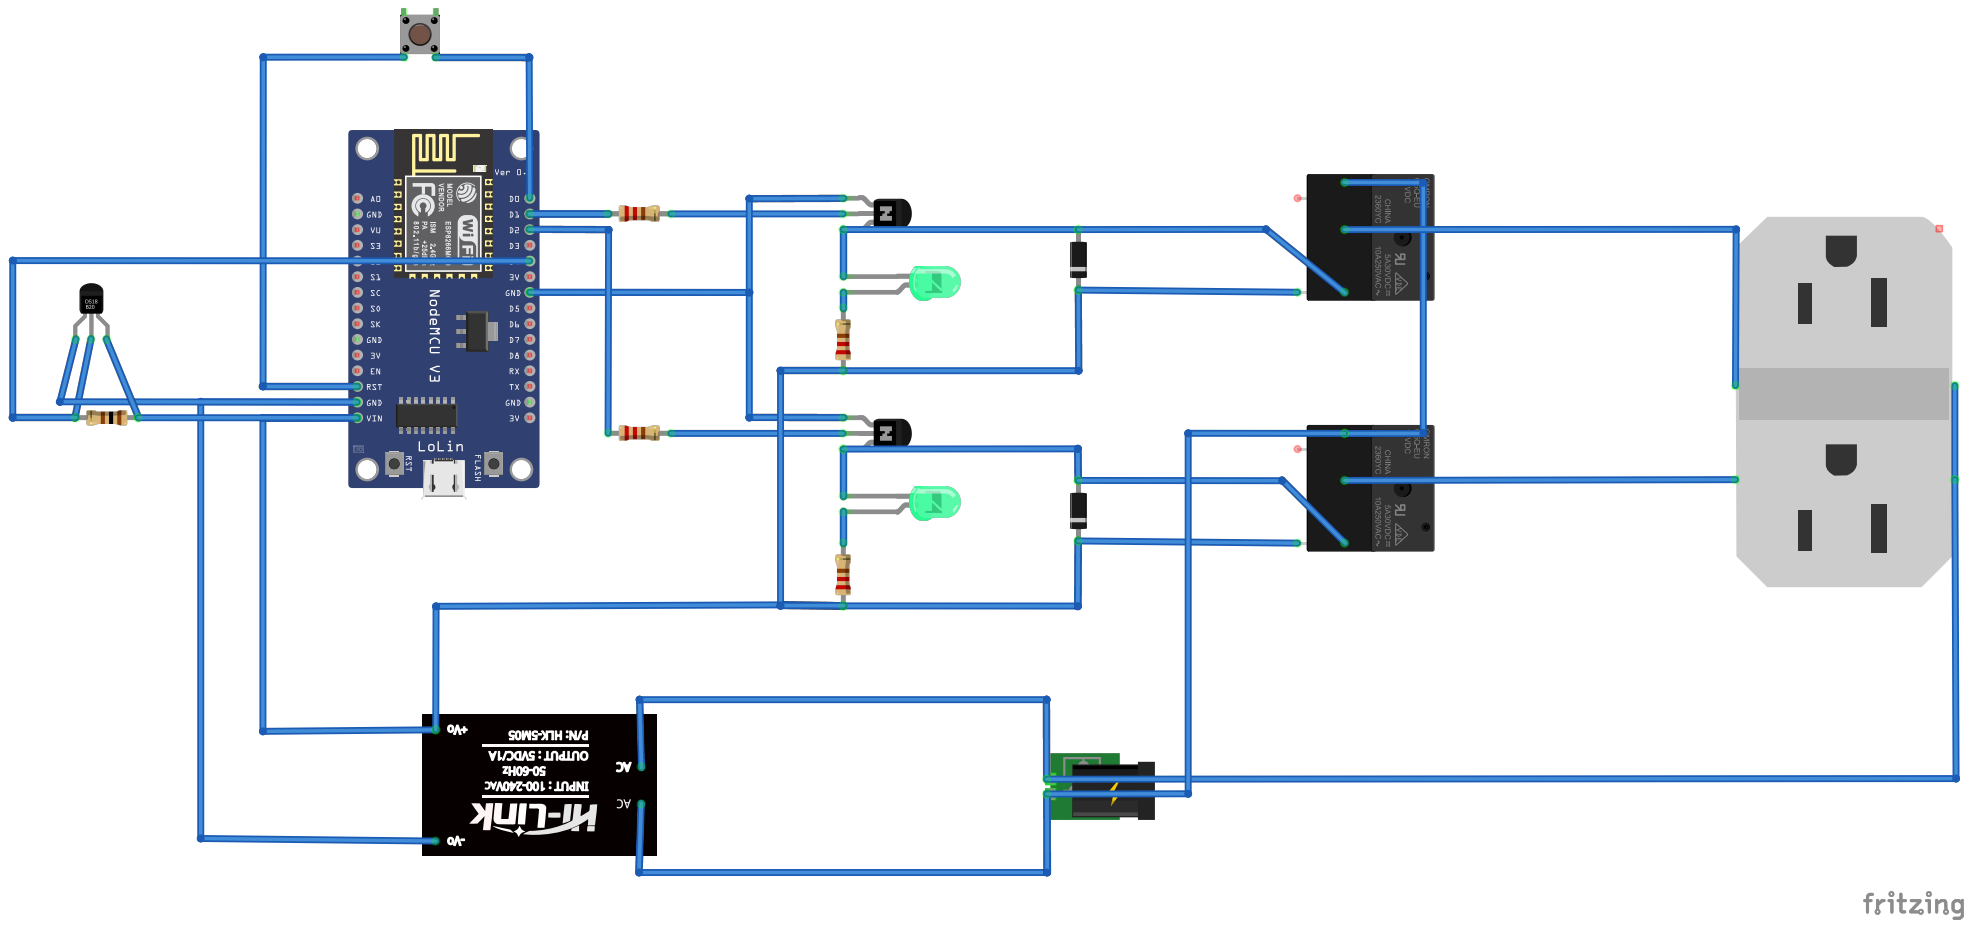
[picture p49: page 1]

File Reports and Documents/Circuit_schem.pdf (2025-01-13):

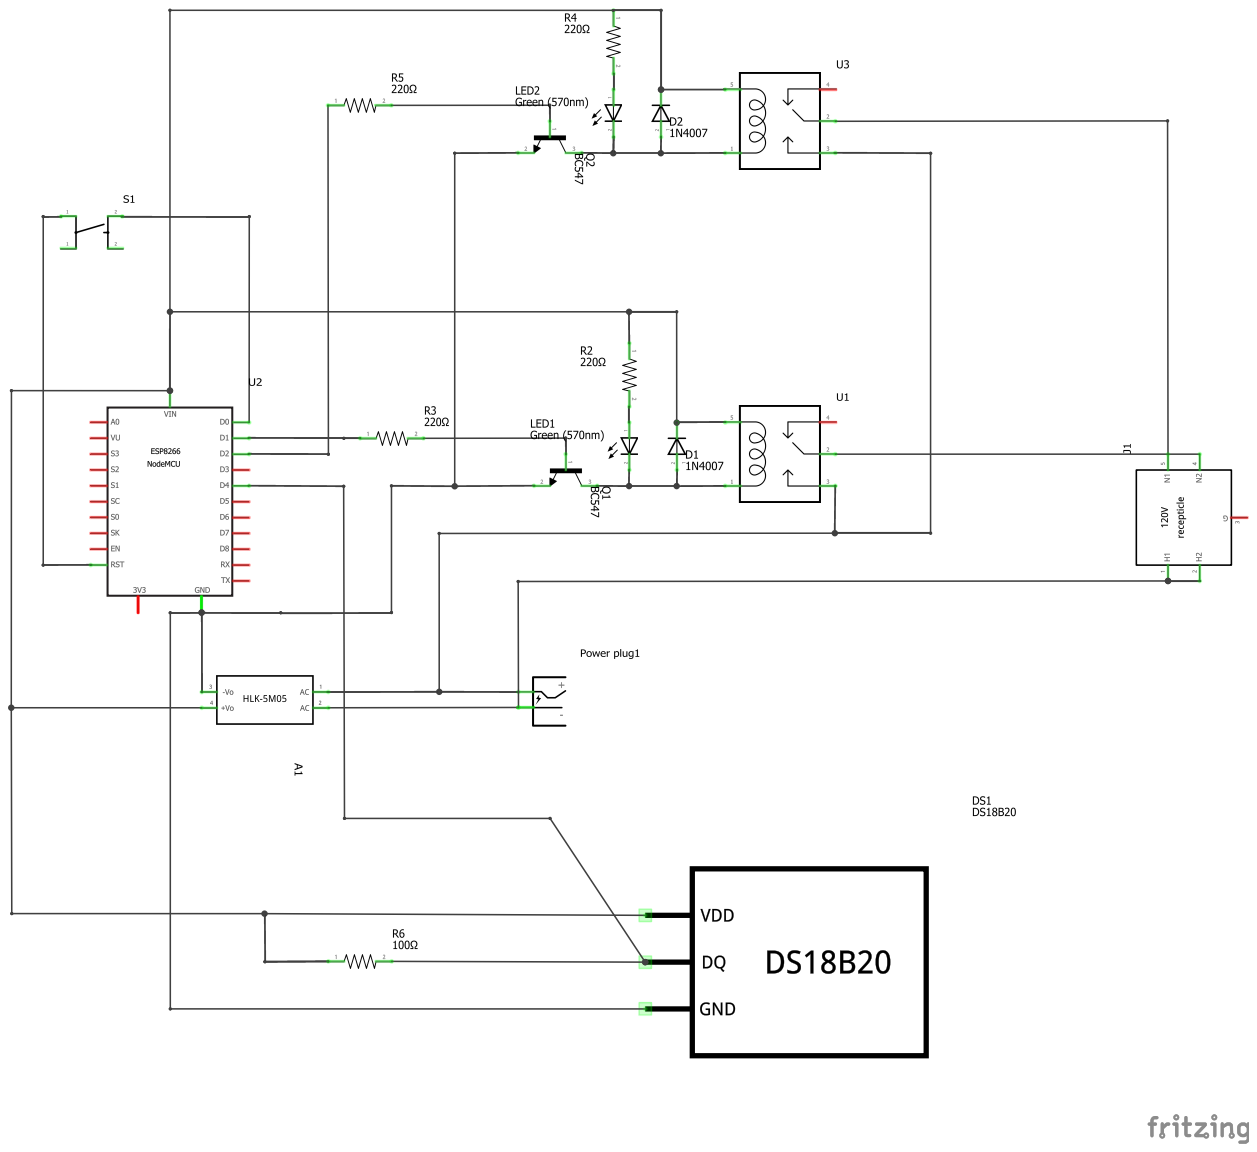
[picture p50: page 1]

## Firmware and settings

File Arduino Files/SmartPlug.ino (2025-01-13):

#define BLYNK_TEMPLATE_ID "TMPL6UEaxh_Xj"
#define BLYNK_DEVICE_NAME "Home Automation"

#define BLYNK_FIRMWARE_VERSION    "0.1.0"
#define BLYNK_PRINT Serial

#define APP_DEBUG
#define USE_NODE_MCU_BOARD

#include "BlynkEdgent.h"

#include <OneWire.h>
#include<DallasTemperature.h> 
#include <NTPClient.h>
#include <WiFiUdp.h>

#define ONE_WIRE_BUS 2 // DS18B20 on arduino pin2 corresponds to D4 on physical board

OneWire oneWire(ONE_WIRE_BUS);
DallasTemperature DS18B20(&oneWire);
int temp_0;

int startTime1;
int endTime1;
int startTime2;
int endTime2;

WiFiUDP ntpUDP;
const long utcOffsetInSeconds = 19800;
NTPClient timeClient(ntpUDP, "asia.pool.ntp.org", utcOffsetInSeconds);

#define RELAY_PIN_1               5 // D1
#define RELAY_PIN_2               4 // D2   

#define VIRTUAL_RELAY_1                           V0
#define VIRTUAL_RELAY_2                           V1
#define TEMP_SENSOR                               V10

#define BUTTON_NUM                                 2
#define BUTTON_NO_PRESS                           -1
#define BUTTON_PLUG_1                              0
#define BUTTON_PLUG_2                              1

#define ON                                         0
#define OFF                                        1

unsigned short gusIsRelay_1_On = OFF;
unsigned short gusIsRelay_2_On = OFF;
unsigned short gusIsBut_Pressed = 0;

void setup()
{
  Serial.begin(115200);
  delay(100);
  
  BlynkEdgent.begin(); 
  DS18B20.begin();
  timeClient.begin();
  timer.setInterval(1000L, getSendData);
  
  pinMode(RELAY_PIN_1, OUTPUT);
  pinMode(RELAY_PIN_2, OUTPUT);

  vRelay_Control(BUTTON_PLUG_1, OFF);
  vRelay_Control(BUTTON_PLUG_2, OFF);
  vBlynk_Write_Button_State(BUTTON_PLUG_1, OFF);
  vBlynk_Write_Button_State(BUTTON_PLUG_2, OFF);
}

void loop() 
{
  short sBut = BUTTON_NO_PRESS;
  timer.run(); // Initiates SimpleTimer
  BlynkEdgent.run();
  
  if(sBut == BUTTON_PLUG_1)
  {
    if(gusIsBut_Pressed == 0)
    {
      if(gusIsRelay_1_On == ON)
      {
        vRelay_Control(sBut, OFF);
        vBlynk_Write_Button_State(sBut, OFF);
      }
      else 
      {
        vRelay_Control(sBut, ON);
        vBlynk_Write_Button_State(sBut, ON);
      }
      gusIsBut_Pressed = 1;
    }
  }
  else if(sBut == BUTTON_PLUG_2)
  {
    if(gusIsBut_Pressed == 0)
    {
      if(gusIsRelay_2_On == ON)
      {
        vRelay_Control(sBut, OFF);
        vBlynk_Write_Button_State(sBut, OFF);
      }
      else 
      {
        vRelay_Control(sBut, ON);
        vBlynk_Write_Button_State(sBut, ON);
      }
      gusIsBut_Pressed = 1; 
    }
  }
  else 
  {
    gusIsBut_Pressed = 0;
  }

  timeClient.update();
  int HH = timeClient.getHours();
  int MM = timeClient.getMinutes();
  int SS = timeClient.getSeconds();
  int server_time = 3600*HH + 60*MM + SS;

   if(startTime1 == server_time)
   {
    digitalWrite(RELAY_PIN_1, HIGH);
    Blynk.virtualWrite(VIRTUAL_RELAY_1, 1);
   }

   if(startTime2 == server_time)
   {
   digitalWrite(RELAY_PIN_2, HIGH);
   Blynk.virtualWrite(VIRTUAL_RELAY_2, 1);
   }

   if(endTime1 == server_time)
   {
   digitalWrite(RELAY_PIN_1, LOW);
   Blynk.virtualWrite(VIRTUAL_RELAY_1, 0);
   }

   if(endTime2 == server_time)
   {
   digitalWrite(RELAY_PIN_2, LOW);
   Blynk.virtualWrite(VIRTUAL_RELAY_2, 0);
   }

}

void getSendData()
{
  DS18B20.requestTemperatures(); 
  temp_0 = DS18B20.getTempCByIndex(0); // Sensor 0 will capture Temp in Celcius 
  Blynk.virtualWrite(TEMP_SENSOR, temp_0); //virtual pin V10
  //Serial.println(temp_0);
}

 
BLYNK_WRITE(VIRTUAL_RELAY_1)
{
  short sVirtual_Status = 0;
  sVirtual_Status = param.asInt();
  vRelay_Control(BUTTON_PLUG_1,sVirtual_Status);
}
BLYNK_WRITE(VIRTUAL_RELAY_2)
{
  short sVirtual_Status = 0;
  sVirtual_Status = param.asInt();
  vRelay_Control(BUTTON_PLUG_2,sVirtual_Status);
}

BLYNK_WRITE(V4){
 startTime1 = param[0].asInt();
 endTime1 = param[1].asInt();
 if(startTime1 == 0 && endTime1 == 0)
 {
  startTime1 = 999999;
  endTime1 = 999999;
 }
}

BLYNK_WRITE(V5){
 startTime2 = param[0].asInt();
 endTime2 = param[1].asInt();
 if(startTime2 == 0 && endTime2 == 0)
 {
  startTime2 = 999999;
  endTime2 = 999999;
 }
}

void vRelay_Control(short sBut, short sOnOff)
{
  if(sOnOff == ON)
  {
    if(sBut == BUTTON_PLUG_1)
    {
      digitalWrite(RELAY_PIN_1, LOW);
      gusIsRelay_1_On = ON;
    }
    else if(sBut == BUTTON_PLUG_2)
    {
      digitalWrite(RELAY_PIN_2, LOW);
      gusIsRelay_2_On = ON;
    }
  }
  else 
  {
    if(sBut == BUTTON_PLUG_1)
    {
      digitalWrite(RELAY_PIN_1, HIGH);
      gusIsRelay_1_On = OFF;
    }
    else if(sBut == BUTTON_PLUG_2)
    {
      digitalWrite(RELAY_PIN_2, HIGH);
      gusIsRelay_2_On = OFF;
    }
  }
}

short sStatus = BUTTON_NO_PRESS;

void vBlynk_Write_Button_State(short sBut, short sStatus)
{
  if(sBut == BUTTON_PLUG_1)
  {
    Blynk.virtualWrite(VIRTUAL_RELAY_1, sStatus);
  }
  else 
  {
    Blynk.virtualWrite(VIRTUAL_RELAY_2, sStatus);
  }
}

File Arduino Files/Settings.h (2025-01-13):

/*
 * General options
 */

#define BOARD_HARDWARE_VERSION        "1.0.0"

/*
 * Board configuration (see examples below).
 */

#if defined(USE_NODE_MCU_BOARD)

  #warning "NodeMCU board selected"

  // Example configuration for NodeMCU v1.0 Board
  #define BOARD_BUTTON_PIN            0
  #define BOARD_BUTTON_ACTIVE_LOW     true

  #define BOARD_LED_PIN_R             D8
  #define BOARD_LED_PIN_G             D7
  #define BOARD_LED_PIN_B             D7
  #define BOARD_LED_INVERSE           false
  #define BOARD_LED_BRIGHTNESS        64

#elif defined(USE_SPARKFUN_BLYNK_BOARD)

  #warning "Sparkfun Blynk board selected"

  // Example configuration for SparkFun Blynk Board
  #define BOARD_BUTTON_PIN            0
  #define BOARD_BUTTON_ACTIVE_LOW     true

  #define BOARD_LED_PIN_WS2812        4
  #define BOARD_LED_BRIGHTNESS        64

#elif defined(USE_WITTY_CLOUD_BOARD)

  #warning "Witty Cloud board selected"

  // Example configuration for Witty cloud Board
  #define BOARD_BUTTON_PIN            4
  #define BOARD_BUTTON_ACTIVE_LOW     true

  #define BOARD_LED_PIN_R             15
  #define BOARD_LED_PIN_G             12
  #define BOARD_LED_PIN_B             13
  #define BOARD_LED_INVERSE           false
  #define BOARD_LED_BRIGHTNESS        64

#else

  // Custom board configuration
  #define BOARD_BUTTON_PIN            0                     // Pin where user button is attached
  #define BOARD_BUTTON_ACTIVE_LOW     true                  // true if button is "active-low"

  #define BOARD_LED_PIN               15                    // Set LED pin - if you have a single-color LED attached
  //#define BOARD_LED_PIN_R           15                    // Set R,G,B pins - if your LED is PWM RGB 
  //#define BOARD_LED_PIN_G           12
  //#define BOARD_LED_PIN_B           13
  //#define BOARD_LED_PIN_WS2812      4                     // Set if your LED is WS2812 RGB
  #define BOARD_LED_INVERSE           false                 // true if LED is common anode, false if common cathode
  #define BOARD_LED_BRIGHTNESS        64                    // 0..255 brightness control

#endif


/*
 * Advanced options
 */

#define BUTTON_HOLD_TIME_INDICATION   3000
#define BUTTON_HOLD_TIME_ACTION       10000

#define BOARD_PWM_MAX                 1023

#define CONFIG_AP_URL                 "blynk.setup"
#define CONFIG_DEFAULT_SERVER         "blynk.cloud"
#define CONFIG_DEFAULT_PORT           443

#define WIFI_NET_CONNECT_TIMEOUT      30000
#define WIFI_CLOUD_CONNECT_TIMEOUT    60000
#define WIFI_AP_CONFIG_PORT           80
#define WIFI_AP_IP                    IPAddress(192, 168, 4, 1)
#define WIFI_AP_Subnet                IPAddress(255, 255, 255, 0)
//#define WIFI_CAPTIVE_PORTAL_ENABLE

#define USE_TICKER
//#define USE_TIMER_ONE
//#define USE_TIMER_THREE

#define BLYNK_NO_DEFAULT_BANNER

#if defined(APP_DEBUG)
  #define DEBUG_PRINT(...) BLYNK_LOG1(__VA_ARGS__)
#else
  #define DEBUG_PRINT(...)
#endif

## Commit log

2025-01-13 Added the Core and Cavity design of the Mold
2025-01-13 Added the Enclosure Design of the Smart Plug
2025-01-13 Added the PCB Design Files of the Smart Plug
2025-01-13 Added Schematics and Block Diagram
2025-01-13 Added the Altium Design Files
    [Smart_Plug(Upadated01).PcbDoc, Smart_Plug(Upadated01).PrjPcb, Smart_Plug(Upadated01).SchDoc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]
2025-01-13 Added the Gerber Files of the PCB
    [Smart_Plug(Upadated01).GBL, Smart_Plug(Upadated01).GBS, Smart_Plug(Upadated01).GTL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]
2025-01-13 Added the Mold Design Files
    [C&C_Design.SLDPRT, Cavity.SLDPRT, Core.SLDPRT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]
2025-01-13 Added the Final Product Enclosure Design Files
    [Assembled_Enclosure.SLDASM, Bottom_Case.SLDPRT, Top_Lid.SLDPRT]
